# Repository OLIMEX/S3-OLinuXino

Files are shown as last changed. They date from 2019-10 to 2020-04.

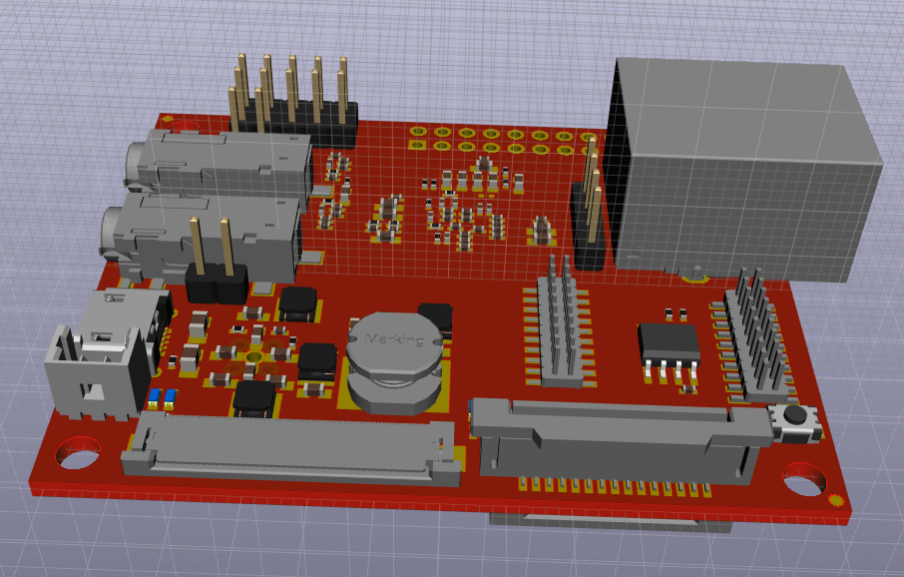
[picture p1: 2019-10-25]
HARDWARE/S3-OLinuXino-Rev_A-preliminary/images/img2.png

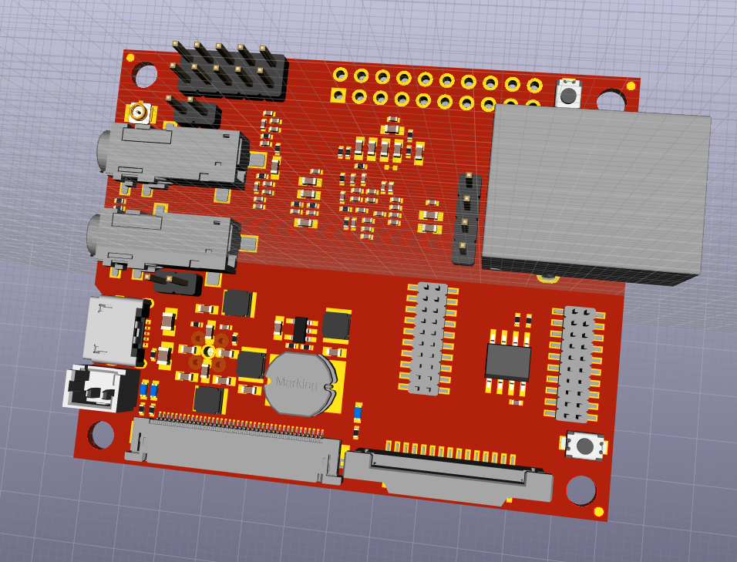
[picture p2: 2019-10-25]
HARDWARE/S3-OLinuXino-Rev_A-preliminary/images/img1.png

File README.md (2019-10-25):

# S3-OLinuXino
IP Camera with S3 SOC from Allwinner, PoE 100Mbit, LCD, micro SD, Flash

This board has:
- Allwinner S3 Cortex-A7 running at 1.2Ghz
- 1Gb DDR3 RAM inside S3 SOC up to 1333Mhz
- 100Mb Ethernet interface with PoE option
- NAND/eMMC/SPI Flash on socket
- WiFi / BT module with RTL8723BS 
- Audio In and Out
- UEXT connector
- Configuration EEPROM
- LCD connector for LCD-OLinuXino
- MIPI camera connector
- CSI camera connector
- Dimensions: 60 x 50 mm

# License
- Hardware is with CERN OHL v1.2 license
- Software is with GPLv3 license
- Documentation is with CC BY-SA 4.0 license

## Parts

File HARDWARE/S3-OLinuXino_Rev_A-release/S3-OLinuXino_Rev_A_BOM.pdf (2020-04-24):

S3-OLinuXino_Rev_A_BOM | 01/03/2020
Qty | Designation | Package | Designator
2 | 0R/R0402(Board_Mounted) | R_0402_5MIL_0R(Board_Mounted) | R34,R53
1 | 0.03R/1%/R1206 | R_1206_5MIL_DWS | R38
10 | 22R/R0402 | R_0402_5MIL_DWS | R8,R9,R12,R20,R22,R50,R54,R55,R62,R63
2 | 240R/1%/R0402 | R_0402_5MIL_DWS | R27,R28
1 | 470R/R0402 | R_0402_5MIL_DWS | R57
1 | 1.1k/1%/R0402 | R_0402_5MIL_DWS | R40
20 | 2.2k/R0402 | R_0402_5MIL_DWS | R1,R2,R3,R4,R5,R6,R14,R15,R16,R18,R21, R24,R25,R29,R30,R35,R47,R52,R58,R59
1 | 3.32k/1%/R0402 | R_0402_5MIL_DWS | R43
2 | 3.9k/1%/R0402 | R_0402_5MIL_DWS | R41,R45
1 | 4.99k/1%/R0402 | R_0402_5MIL_DWS | R42
1 | 6.04k/1%/R0402 | R_0402_5MIL_DWS | R31
1 | 8.25k/1%/R0402 | R_0402_5MIL_DWS | R44
10 | 10k/R0402 | R_0402_5MIL_DWS | R7,R11,R26,R32,R37,R39,R46,R48,R60,R61
1 | 100k/R0402 | R_0402_5MIL_DWS | R10
3 | 200k/1%/R0402 | R_0402_5MIL_DWS | R17,R19,R51
1 | 10M/R0402 | R_0402_5MIL_DWS | R33
1 | RA1206_(4X0603)_4B8_51R | RA1206_(4X0603)_4B8_xx | RM4
3 | RA1206_(4x0603)_4B8_100k | RA1206_(4X0603)_4B8_xx | RM3,RM2,RM1
1 | 0.8pF/50V/+-0.25pF/COG/C0402 | C_0402_5MIL_DWS | C11
1 | 1.5pF/50V/+-0.25pF/COG/C0402 | C_0402_5MIL_DWS | C13
1 | 10pF/50V/5%/COG/C0402 | C_0402_5MIL_DWS | C10
2 | 22pF/50V/5%/COG/C0402 | C_0402_5MIL_DWS | C51,C52
6 | 33pF/50V/5%/COG/C0402 | C_0402_5MIL_DWS | C53,C54,C93,C96,C97,C98
1 | 1nF/50V/10%/X7R/C0402 | C_0402_5MIL_DWS | C21
1 | 1nF/2kV/10%/X7R/C1206 | C_1206_5MIL_DWS_ISO | C65
44 | 100nF/10V/10%/X7R/C0402 | C_0402_5MIL_DWS | C1,C3,C4,C7,C9,C33,C16,C17,C18,C20,C22, C30,C32,C38,C50,C57,C60,C64,C63,C66, C71,C73,C75,C76,C78,C79,C82,C83,C95, C88,C84,C85,C86,C87,C89,C90,C91,C94, C99,C100,C101,C102,C103,C105
1 | 1uF/10V/20%/X5R/C0603 | C_0603_5MIL_DWS | C42
2 | 2.2uF/6.3V/10%/X5R/C0603 | C_0603_5MIL_DWS | C19,C47
9 | 4.7uF/6.3V/20%/X5R/C0603 | C_0603_5MIL_DWS | C24,C28,C37,C43,C44,C45,C46,C48,C49
20 | 10uF/6.3V/20%/X5R/C0603 | C_0603_5MIL_DWS | C6,C8,C14,C15,C29,C31,C34,C35,C36,C39, C40,C41,C55,C59,C67,C68,C74,C77,C81,C92
9 | 47uF/6.3V/20%/X5R/C0805 | C_0805_5MIL_DWS | C12,C25,C26,C27,C56,C58,C61,C69,C70
1 | 3.3nH/+-0.1nH/L0402 (LQP15MN3N3B02D) | L_0402_5MIL_DWS | L1
3 | 2.2uH/1.5A/72mR/20%/CD32 (SPN30302R2MPTE) | CD32 | L3,L4,L5
1 | 2.2uH/1.5A/DCR=72mR/20%/ 3.00x3.00x1.50mm/CD32 (NR3015T2R2M) | CD32 | L7
1 | 2.2uH/4.5A/28mR/20%/CD75/ 7.8x7.0x5.0mm(YS75-2R2M) | YS75_7X8MM | L6
6 | FB0805\600R\2A | L_0805_5MIL_DWS | L2,L8,L9,L10,L11,L12
2 | 1N5822/SS34/SMA | SMA-KA | D3,D4
1 | 1N5819(S4SOD-123) | SOD-123_1C-2A_KA | D1
1 | IRLML6402(SOT-23) | SOT23 | FET1
1 | SMBJ6.0A | DO214AA_1(K)-2(A) | D2
1 | LED/YELLOW/0603 | LED_0603_KA | CHGLED1
1 | LED\Red\0603 | LED_0603_KA | PWRLED1
1 | LED/Red/0603 | LED_0603_KA | GPIO_LED1
1 | DTA114YKA(SOT-23) | SOT23 | T1
1 | Q32.768kHz/12.5pF/2P/SMD1206 | CM7V-T1A(Crystal_Package-1206_3.20x1.50x0.65mm) | Q1
1 | Q24MHZ/20pF/30ppm/4P/ 3.2x2.5mm | TSX-3.2x2.5mm_GND(3) | Q2
1 | AllWinner-S3(FBGA-234) | FBGA-234(Pitch-0.65mm_Pad-0.3mm_11x11x1.08mm) | U1
1 | SY8089AAAC(SOT23-5) | SOT-23-5 | U5
1 | AXP209(QFN-48) | QFN48-6x6mm-OLIMEX_V2 | U4

S3-OLinuXino_Rev_A_BOM | 01/03/2020
1 | RTL8723BS(ComboModule) | RL-SM02BD(RTL8723BS) | U3
1 | AT24C16C-SSHM-T | SOIC-8_150mil | U2
1 | SY6280AAC(SOT23-5) | SOT-23-5 | U6
1 | MT3608(SOT23-6) | SOT23-6 | U7
1 | [2x(HN1x2)+HN1x4] | PoE[2x(HN1x2)+HN1x4] | PoE1
1 | HN2x5 | HN2x5 | UEXT1
1 | Flash[2x(PA-V16X-2X10-LF)] | Flash[2x(PA-V16X-2X10-LF)] | Flash1
1 | DW02S | LIPO_BAT_VERTICAL_DW02S | LiPo_BAT1
1 | FPV-WZA21-40-LF | FPV-WZA21-40-LF | LCD_CON1
1 | LPJG0926HENL(MagJack_ 10_100_1000_with_PoE) | LPJG0926HENL(MagJack_ 10_100_1000_with_PoE) | LAN1
1 | OV2640(FPV-WZB21-24-LF) | OV2640(FPV-WZB21-24-LF) | CAM1
2 | PJ-W47S-05D2-LF | PJ-W47S-05D2-LF_5PIN_V2 | HEADPHONES/LINEOUT1,MIC/LINEIN1
1 | 1.0mm-pitch_ZIF_SMT-15P | TE_1-1734248-5 | RPi_CAMERA1
1 | MICRO_SD(TFC-WPAPR-08) | TFC-WPAPR-08 | MICRO_SD1
1 | U.FL-R-SMT-1 | U.FL-R-SMT-1 | ANT1
1 | MICRO_USB\MISB-SWMM-5B_LF | USB-MICRO_MISB-SWMM-5B_LF | USB-OTG1
2 | IT-1185AU2-160G-G-TR | IT1185AU2_V2 | PWR1,RST1
2 | Soldered(1-2);Opened(2-3) | SJ_2_SMALL | HPHONEOUTL/LINEOUTL1, HPHONEOUTR/LINEOUTR1
2 | Opened(2-3);Soldered(1-2) | SJ_2_SMALL | LINEINR/MICIN1,LINEINL/MICIN1
1 | NA(HN2x10) | HN2x10 | EXT1
1 | NA(15pF/C0402) | C_0402_5MIL_DWS | C104
1 | NA(10uF/6.3V/20%/X5R/C0603) | C_0603_5MIL_DWS | C23
2 | NA | R_0402_5MIL_DWS | R13,R49
2 | NA/R0402 | R_0402_5MIL_DWS | R64,R56
1 | NA(2.2k/R0402) | R_0402_5MIL_DWS | R36

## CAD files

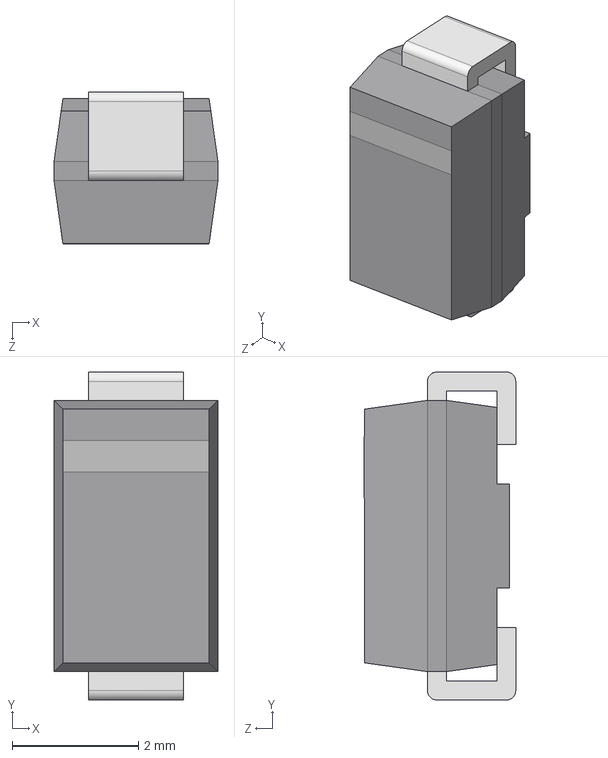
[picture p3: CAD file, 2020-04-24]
HARDWARE/S3-OLinuXino-Rev_A-preliminary/3d/DO-214AC_SMA.step
2.60 x 5.20 x 2.40 mm

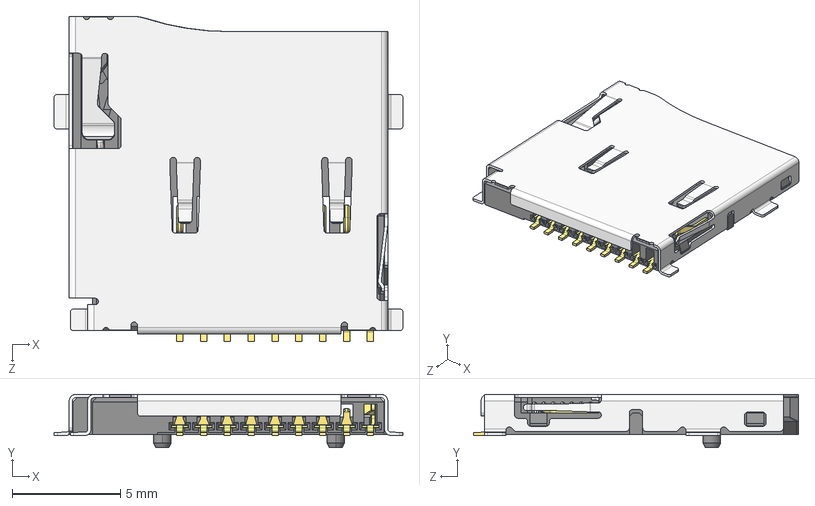
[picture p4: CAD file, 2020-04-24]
HARDWARE/S3-OLinuXino_Rev_A-release/3d/TFC-WPAPR-08---112J-TXAR-R_C_1-1.STEP
16.1 x 2.45 x 15.0 mm

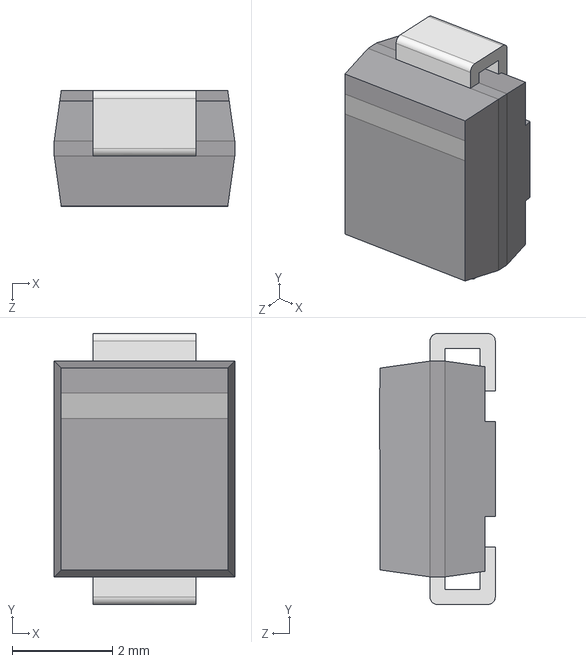
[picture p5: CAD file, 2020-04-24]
HARDWARE/S3-OLinuXino-Rev_A-preliminary/3d/DO-214AA_SMB.step
3.60 x 5.40 x 2.30 mm

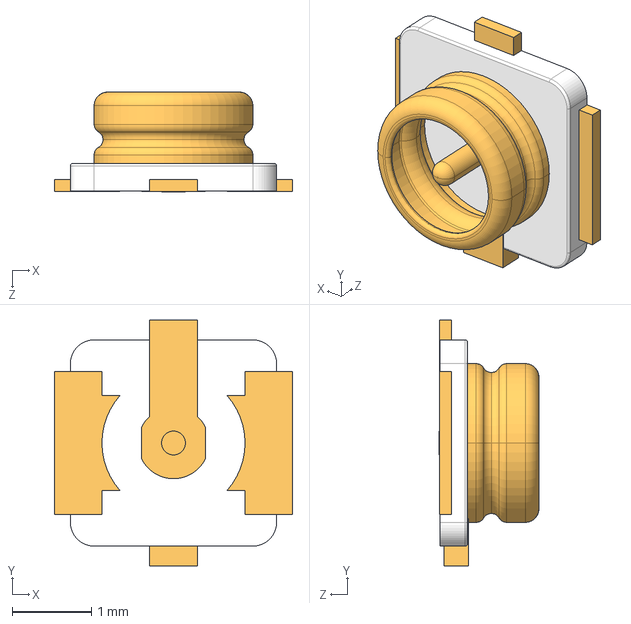
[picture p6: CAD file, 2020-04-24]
HARDWARE/S3-OLinuXino_Rev_A-release/3d/U_FL-R-SMT-1.step
3.00 x 3.10 x 1.26 mm

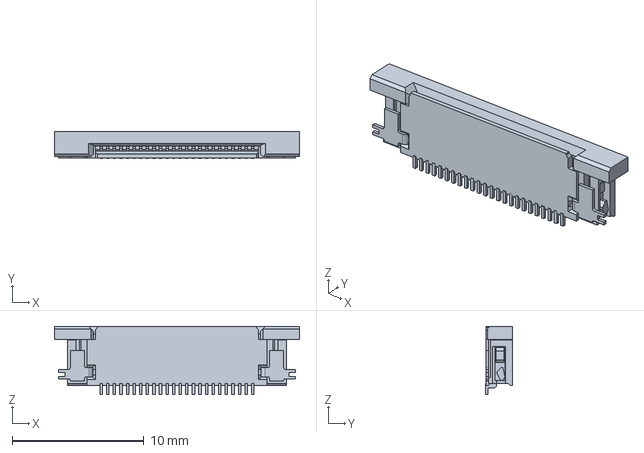
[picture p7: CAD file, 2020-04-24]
HARDWARE/S3-OLinuXino_Rev_A-release/3d/FPV-WZB21-24-LF_Molex-524372433.stp
18.6 x 2.04 x 5.20 mm

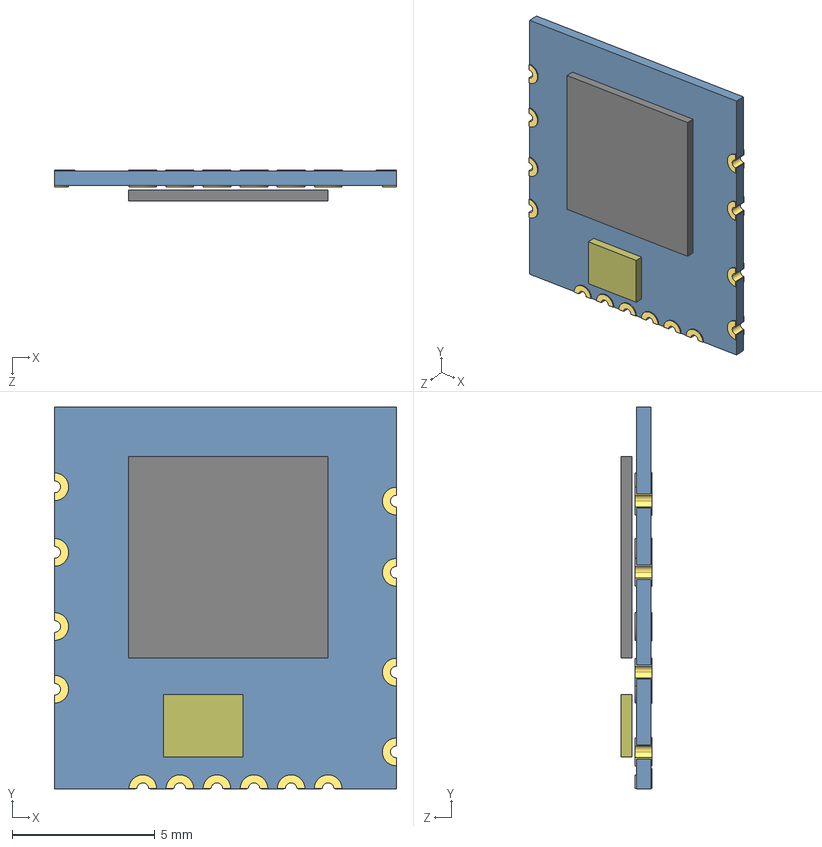
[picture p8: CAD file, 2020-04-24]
HARDWARE/S3-OLinuXino-Rev_A-preliminary/3d/BL-R8723BT1module.STEP
12.0 x 13.4 x 1.10 mm
User Library-BL-R8723BT1 module_Part_113087
User Library-BL-R8723BT1 module_Part_113087_2
User Library-BL-R8723BT1 module_Part_123053
User Library-BL-R8723BT1 module_Part_156259
User Library-BL-R8723BT1 module_Part_126661
User Library-BL-R8723BT1 module_Part_126661_2
User Library-BL-R8723BT1 module_Part_126661_3
User Library-BL-R8723BT1 module_Part_126661_4
User Library-BL-R8723BT1 module_Part_126661_5
User Library-BL-R8723BT1 module_Part_156259_2
User Library-BL-R8723BT1 module_Part_126661_6
User Library-BL-R8723BT1 module_Part_126661_7
User Library-BL-R8723BT1 module_Part_126661_8
User Library-BL-R8723BT1 module_Part_126661_9
User Library-BL-R8723BT1 module_Part_126661_10
User Library-BL-R8723BT1 module_Part_126661_11
User Library-BL-R8723BT1 module_Part_156259_3

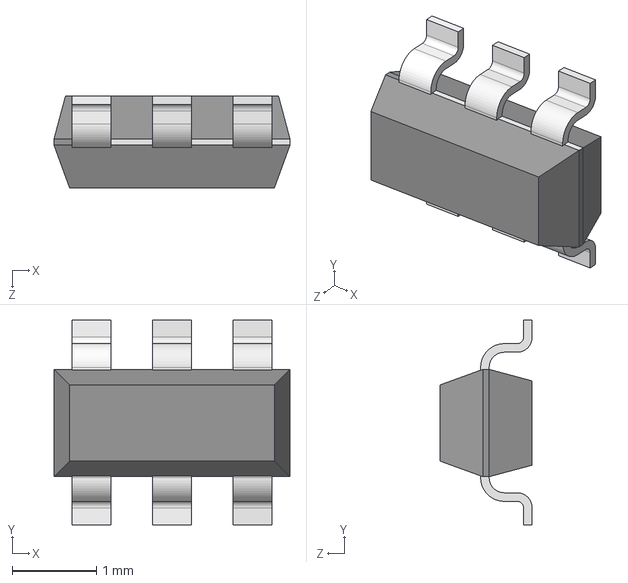
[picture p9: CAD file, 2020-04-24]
HARDWARE/S3-OLinuXino-Rev_A-preliminary/3d/SOT-23-6.step
2.79 x 2.43 x 1.09 mm

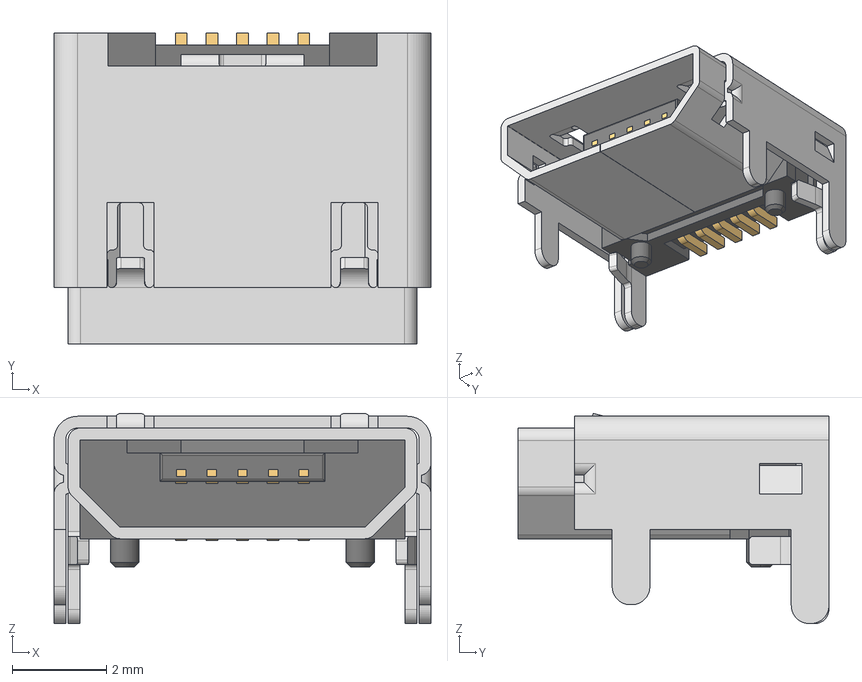
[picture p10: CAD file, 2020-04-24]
HARDWARE/S3-OLinuXino-Rev_A-preliminary/3d/usb_micro_4p.stp
8.00 x 6.60 x 4.46 mm

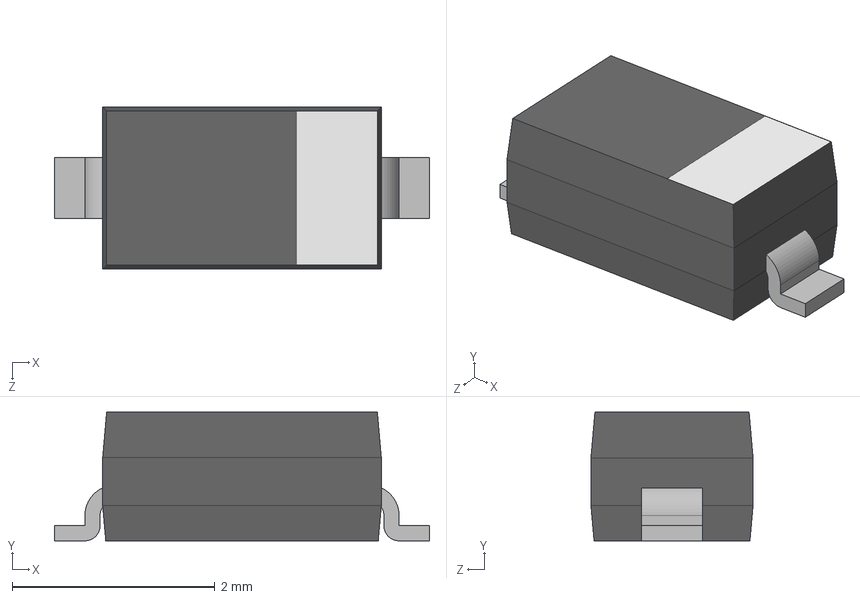
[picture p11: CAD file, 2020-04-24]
HARDWARE/S3-OLinuXino-Rev_A-preliminary/3d/SOD123.step
3.70 x 1.27 x 1.60 mm

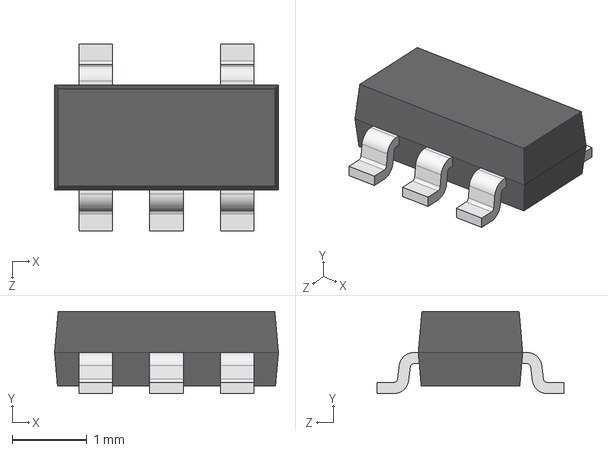
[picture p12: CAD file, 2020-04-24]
HARDWARE/S3-OLinuXino_Rev_A-release/3d/SOT-23-5.step
3.00 x 1.10 x 2.50 mm

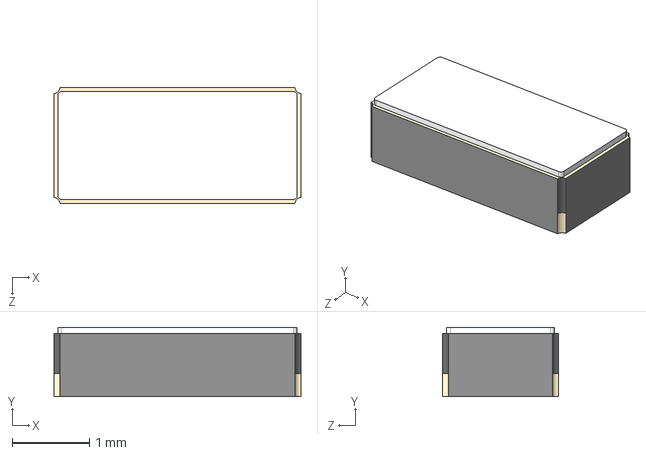
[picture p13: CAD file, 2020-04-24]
HARDWARE/S3-OLinuXino-Rev_A-preliminary/3d/Q32.768kHz_12.5pF_2P_SMD1206---ECS-.327-12.5-34B-C-TR.STEP
3.20 x 0.9 x 1.50 mm

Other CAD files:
HARDWARE/S3-OLinuXino-Rev_A-preliminary/3d/20PinMaleSmt.stp
HARDWARE/S3-OLinuXino-Rev_A-preliminary/3d/BGA-256_11.0x11.0mm_Layout20x20_P0.5mm_Ball0.3mm_Pad0.25mm_NSMD.step
HARDWARE/S3-OLinuXino-Rev_A-preliminary/3d/CUI_SJ-43515TS-SMT-TR.step
HARDWARE/S3-OLinuXino-Rev_A-preliminary/3d/FPV-WZA21-40-LF_Molex-541044033.stp
HARDWARE/S3-OLinuXino-Rev_A-preliminary/3d/HN1x2-PinHeader_1x02_P2.54mm_Vertical.step
HARDWARE/S3-OLinuXino-Rev_A-preliminary/3d/HN1x4-PinHeader_1x04_P2.54mm_Vertical.step
HARDWARE/S3-OLinuXino-Rev_A-preliminary/3d/HN2x5-PinHeader_2x05_P2.54mm_Vertical.step
HARDWARE/S3-OLinuXino-Rev_A-preliminary/3d/L-CD32_shielded.step
HARDWARE/S3-OLinuXino-Rev_A-preliminary/3d/L-CD75(YS75)_7.80x7.00x5.50mm.step
HARDWARE/S3-OLinuXino-Rev_A-preliminary/3d/Molex_PicoBlade_530470210.step
HARDWARE/S3-OLinuXino-Rev_A-preliminary/3d/QFN-48_6x6mm_Pitch-0.4mm.STEP
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

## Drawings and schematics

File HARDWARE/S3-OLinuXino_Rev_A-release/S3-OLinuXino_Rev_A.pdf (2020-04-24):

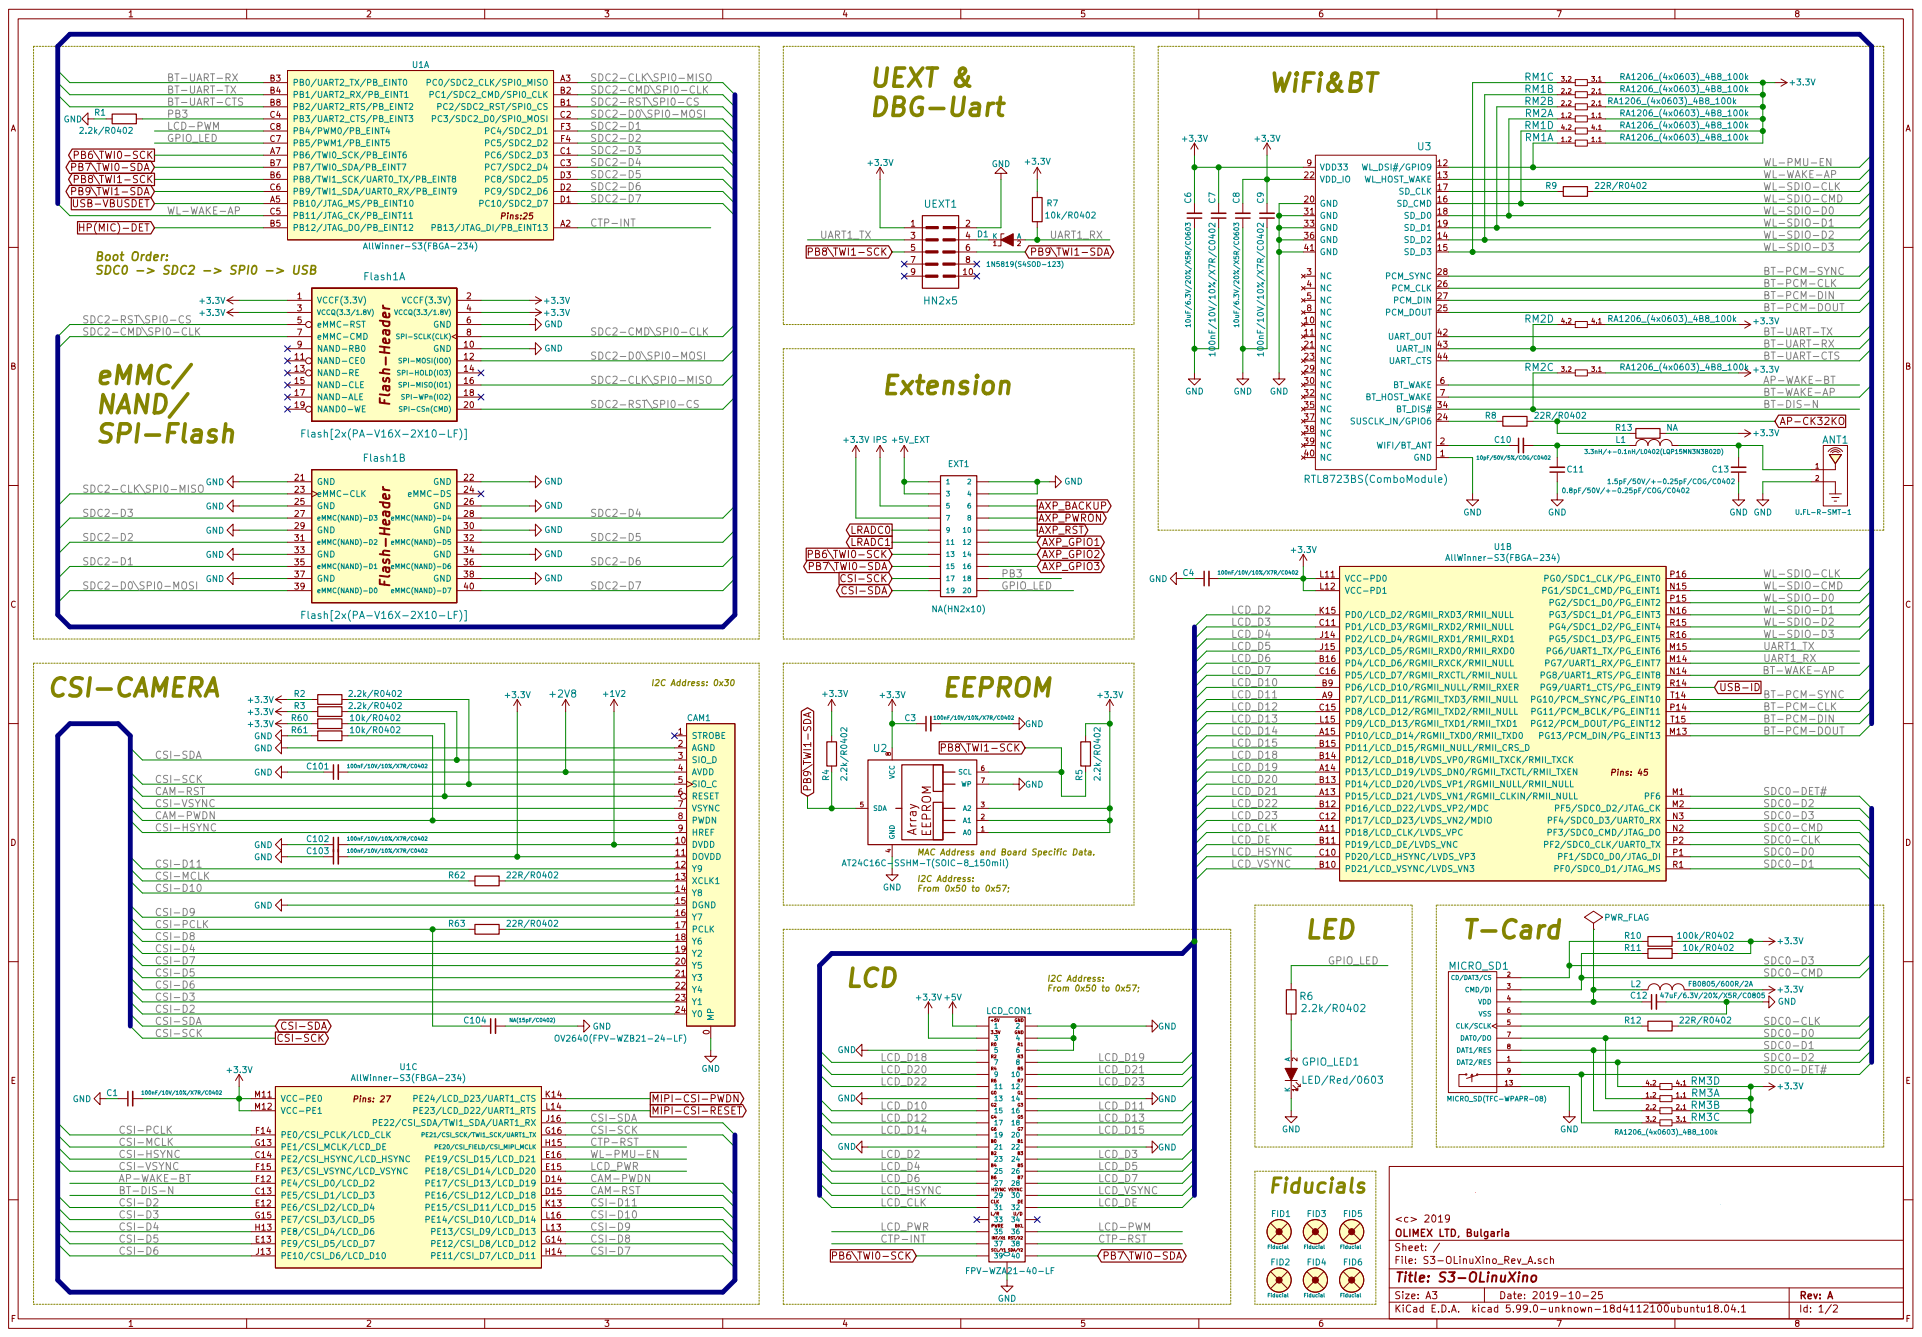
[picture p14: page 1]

BT-UART-RX WL-PMU-EN WL-WAKE-AP WL-SDIO-D3 WL-SDIO-D2 WL-SDIO-D1 WL-SDIO-D0 WL-SDIO-CMD

PB6\TWI0-SCK
PB8\TWI1-SCK
PB9\TWI1-SDA
HP(MIC)-DET USB-VBUSDET

BT-PCM-SYNC
BT-PCM-CLK
BT-PCM-DOUT BT-PCM-DIN

+3.3V GND GND GND GND GND GND

2 ANT1
BT-PCM-DOUT WL-SDIO-CLK

I2C Address: From 0x50 to 0x57; EEPROM

CAM-RST CSI-D7 CSI-D9 CSI-D8 CSI-D10 CSI-D11 CSI-D2 CSI-D3 CSI-D4 CSI-PCLK CSI-VSYNC
CSI-D6 CSI-MCLK CSI-D5 CSI-HSYNC

0 STROBE 1 DVDD 10 DOVDD 11 Y9 12 XCLK1 13 Y8 14 DGND 15 Y7 16 PCLK 17 Y6 18 Y2 19 AGND 2 Y5 20 Y3 21 Y4 22 Y1 23 Y0 24 SIO_D 3 AVDD 4 SIO_C 5 RESET 6 VSYNC 7 PWDN 8 HREF 9 CAM1 OV2640(FPV-WZB21-24-LF)

MAC Address and Board Specific Data. GND

4 SDA 5 SCL 6 WP 7 VCC

2.2k/R0402 MIPI-CSI-RESET MIPI-CSI-PWDN

CSI-MCLK CSI-PCLK

CTP-RST CSI-D9 CAM-PWDN

File: S3-OLinuXino_Rev_A.sch Sheet: / OLIMEX LTD, Bulgaria <c> 2019

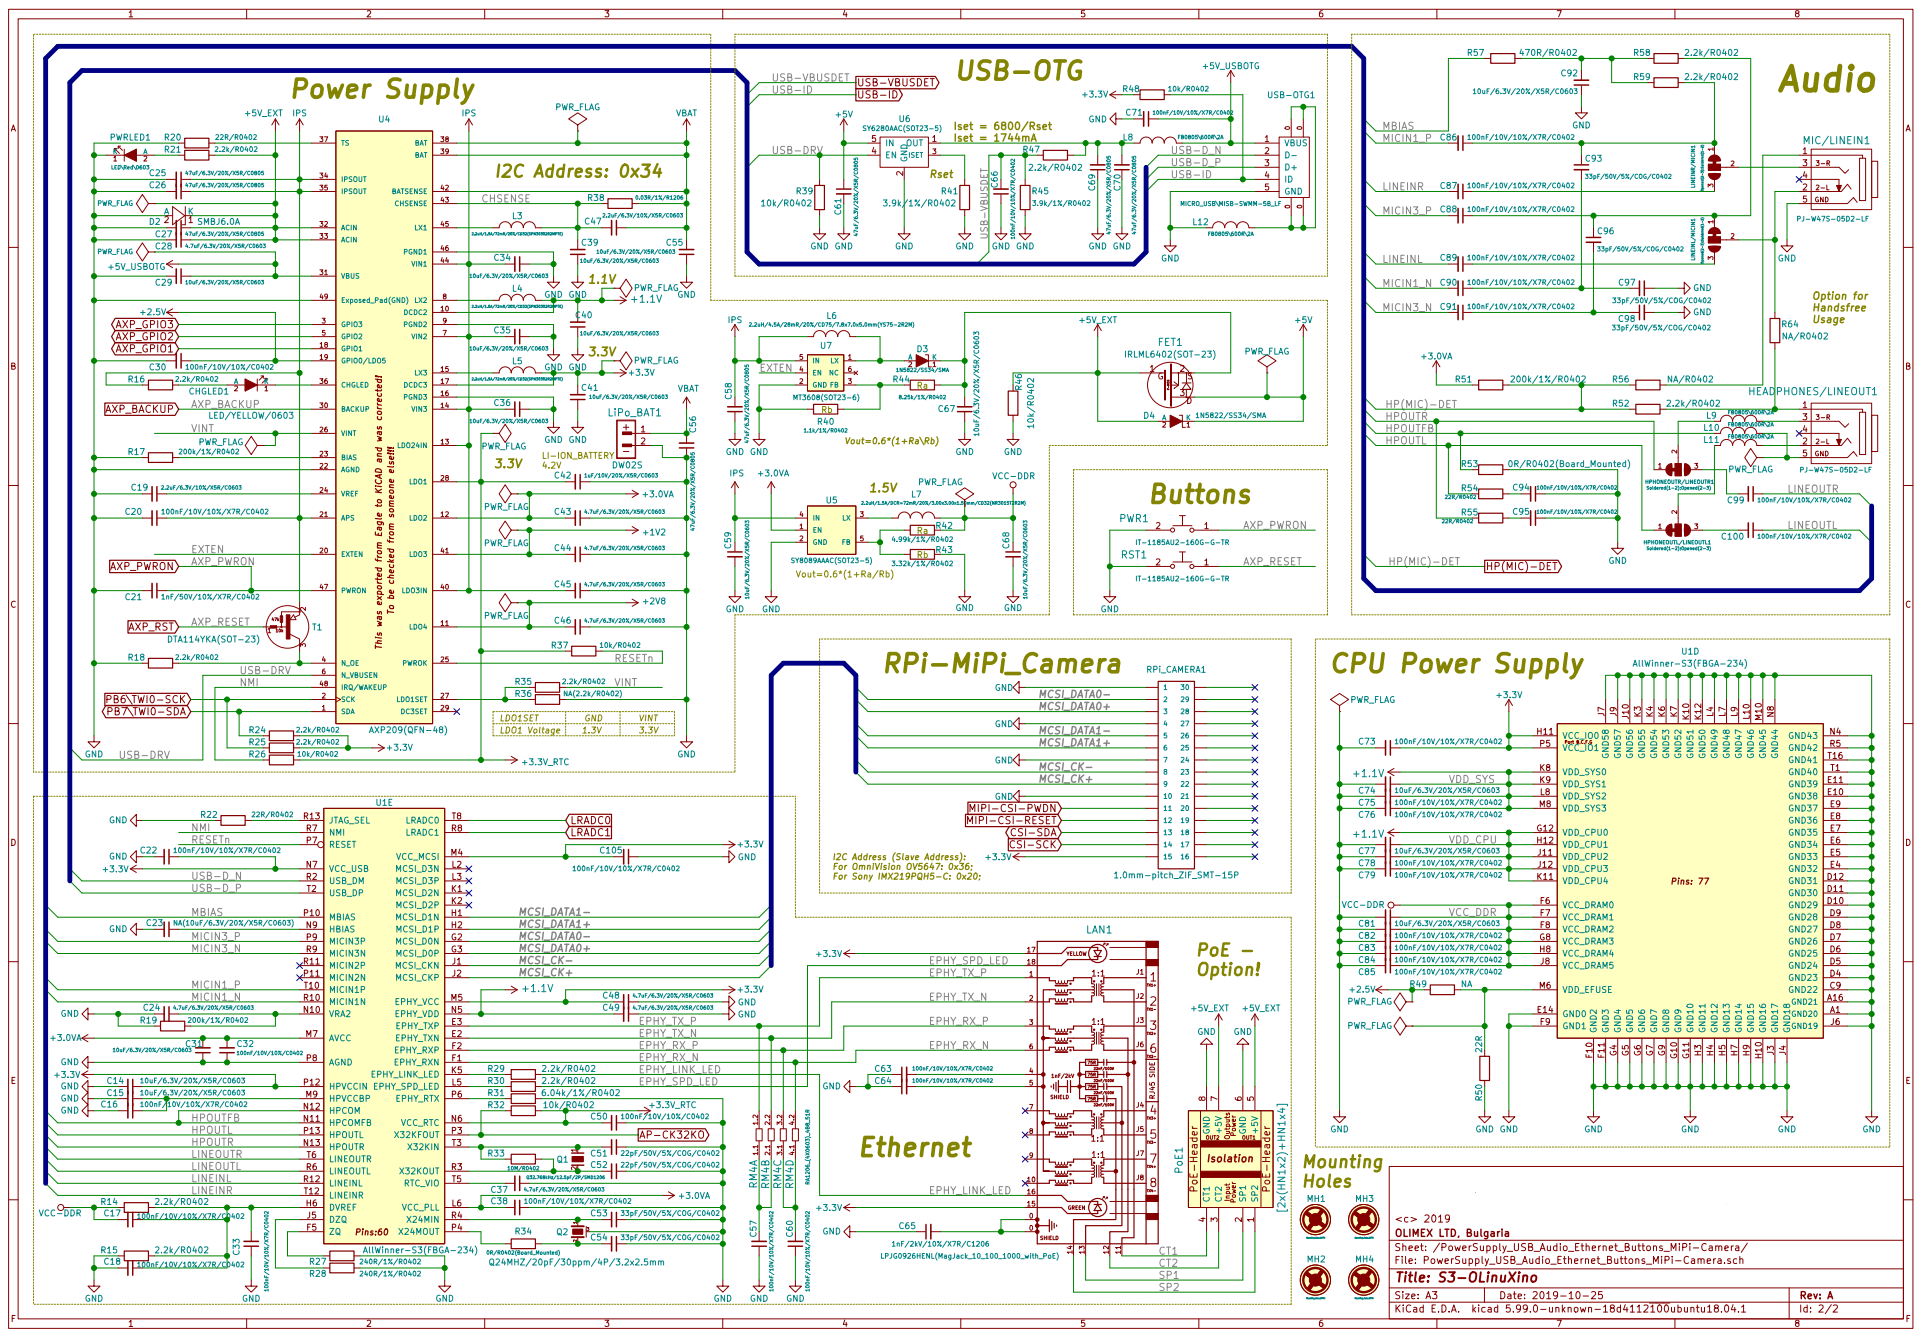
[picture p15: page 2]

File: PowerSupply_USB_Audio_Ethernet_Buttons_MiPi-Camera.sch Sheet: /PowerSupply_USB_Audio_Ethernet_Buttons_MiPi-Camera/ OLIMEX LTD, Bulgaria <c> 2019 Power Supply

33pF/50V/5%/COG/C0402 C97
Option for Handsfree Usage GND GND GND

VCC-DDRR46 10k/R0402 Vout=0.6*(1+Ra\Rb)

CSI-SDA CSI-SCK MCSI_CK- MCSI_DATA1- MCSI_DATA1+ MCSI_CK+ MCSI_DATA0- MCSI_DATA0+

I2C Address (Slave Address): For OmniVision OV5647: 0x36; For Sony IMX219PQH5-C: 0x20; +3.3V_RTC

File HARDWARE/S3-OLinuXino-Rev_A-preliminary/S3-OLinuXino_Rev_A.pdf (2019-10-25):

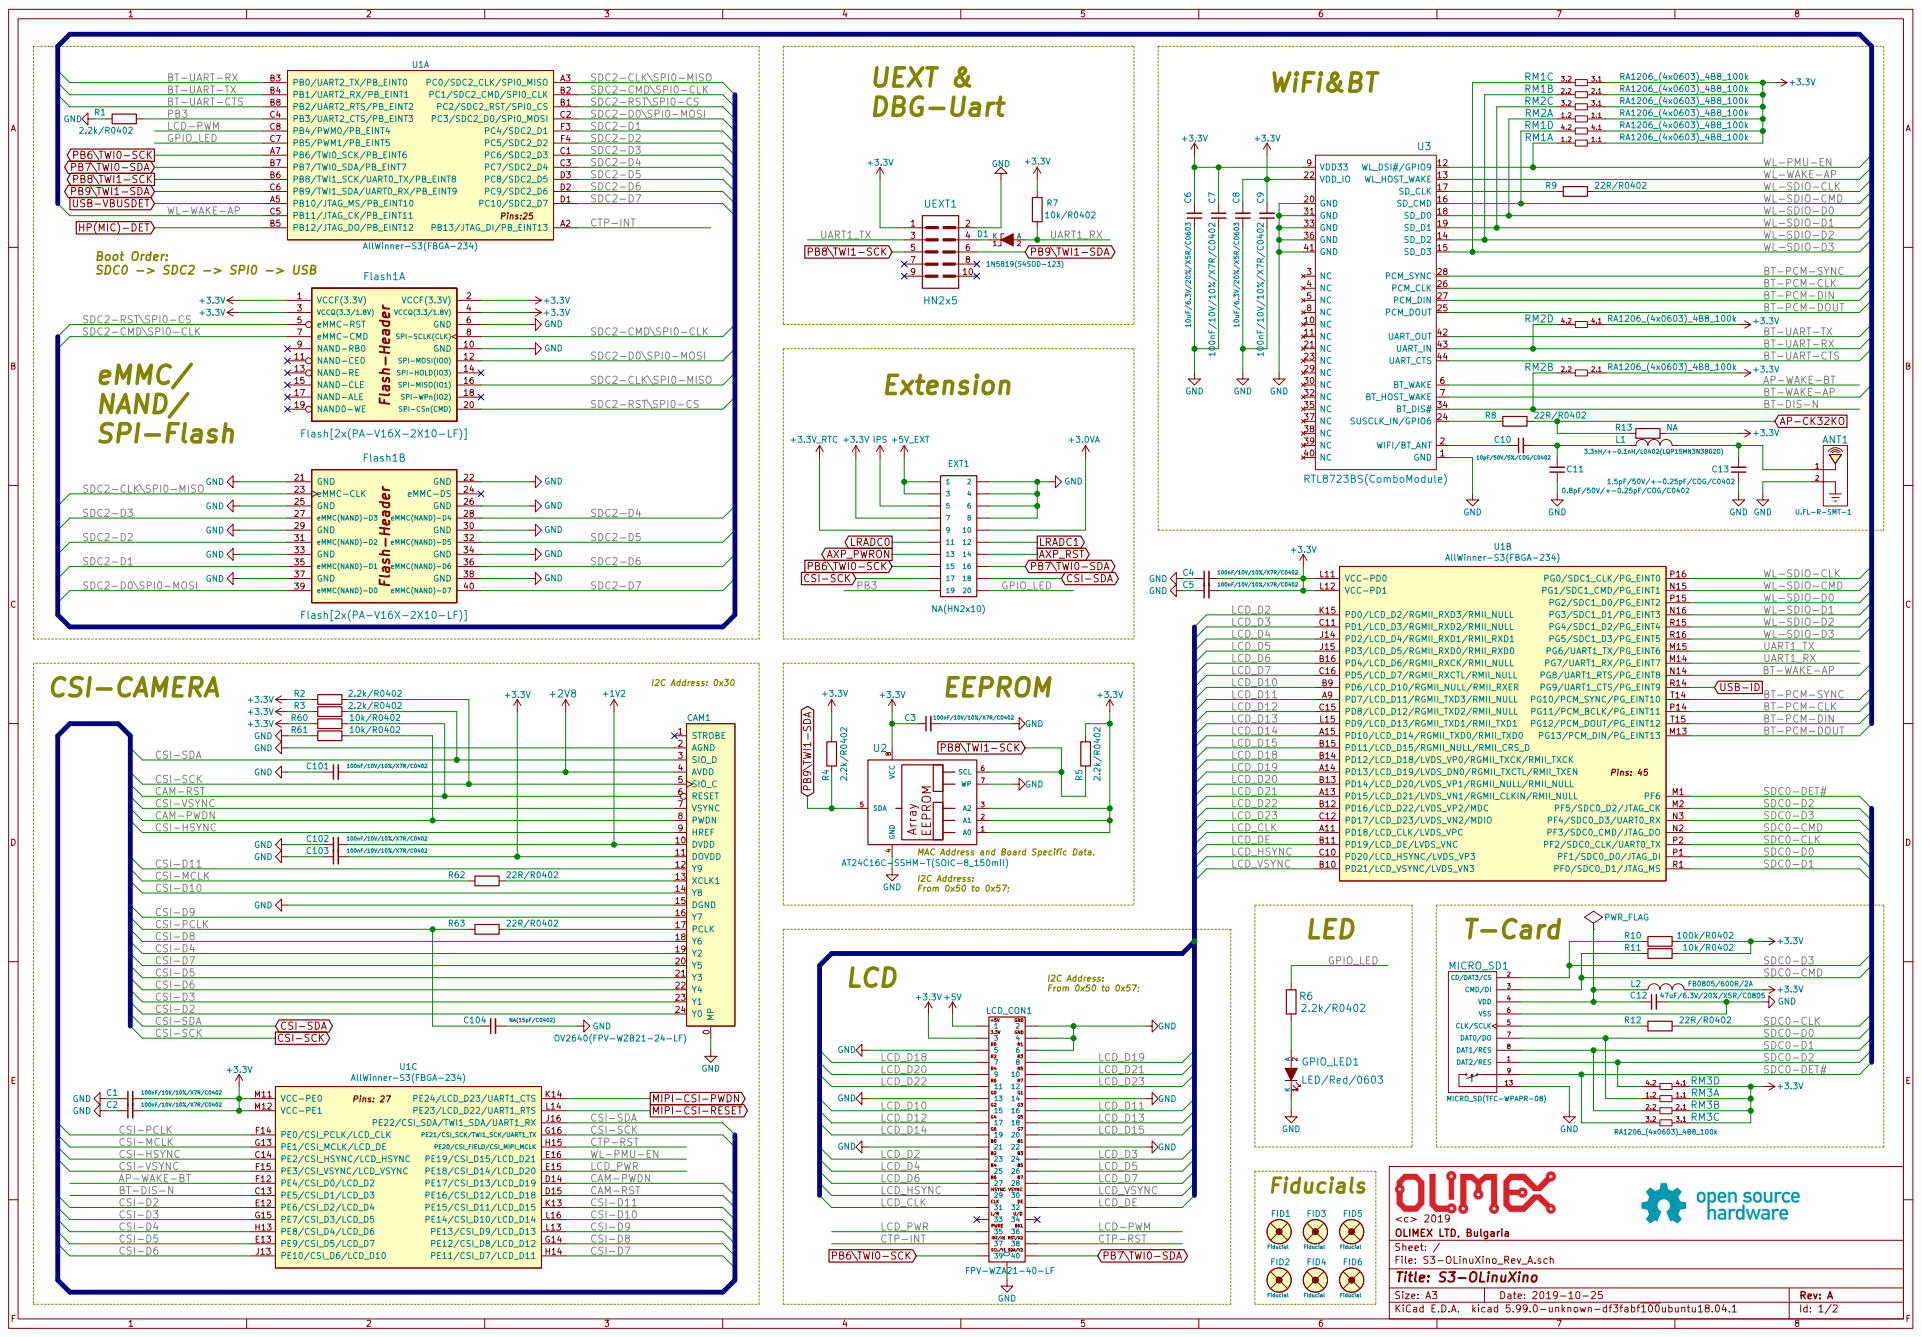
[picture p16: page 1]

BT-UART-RX WL-PMU-EN WL-WAKE-AP WL-SDIO-D3 WL-SDIO-D2 WL-SDIO-D1 WL-SDIO-D0 WL-SDIO-CMD

PB6\TWI0-SCK
PB8\TWI1-SCK
PB9\TWI1-SDA
HP(MIC)-DET USB-VBUSDET

Flash[2x(PA-V16X-2X10-LF)] Boot Order: SDC0 -> SDC2 -> SPI0 -> USB

BT-PCM-SYNC
BT-PCM-CLK
BT-PCM-DOUT BT-PCM-DIN

+3.3V GND GND GND GND GND GND

2 ANT1
BT-PCM-DOUT WL-SDIO-CLK

I2C Address: From 0x50 to 0x57; EEPROM

CAM-RST CSI-D7 CSI-D9 CSI-D8 CSI-D10 CSI-D11 CSI-D2 CSI-D3 CSI-D4 CSI-PCLK CSI-VSYNC
CSI-D6 CSI-MCLK CSI-D5 CSI-HSYNC

0 STROBE 1 DVDD 10 DOVDD 11 Y9 12 XCLK1 13 Y8 14 DGND 15 Y7 16 PCLK 17 Y6 18 Y2 19 AGND 2 Y5 20 Y3 21 Y4 22 Y1 23 Y0 24 SIO_D 3 AVDD 4 SIO_C 5 RESET 6 VSYNC 7 PWDN 8 HREF 9 CAM1 OV2640(FPV-WZB21-24-LF)

MAC Address and Board Specific Data. GND

4 SDA 5 SCL 6 WP 7 VCC

2.2k/R0402 MIPI-CSI-RESET MIPI-CSI-PWDN

CSI-MCLK CSI-PCLK

CTP-RST CSI-D9 CAM-PWDN

File: S3-OLinuXino_Rev_A.sch Sheet: / OLIMEX LTD, Bulgaria <c> 2019

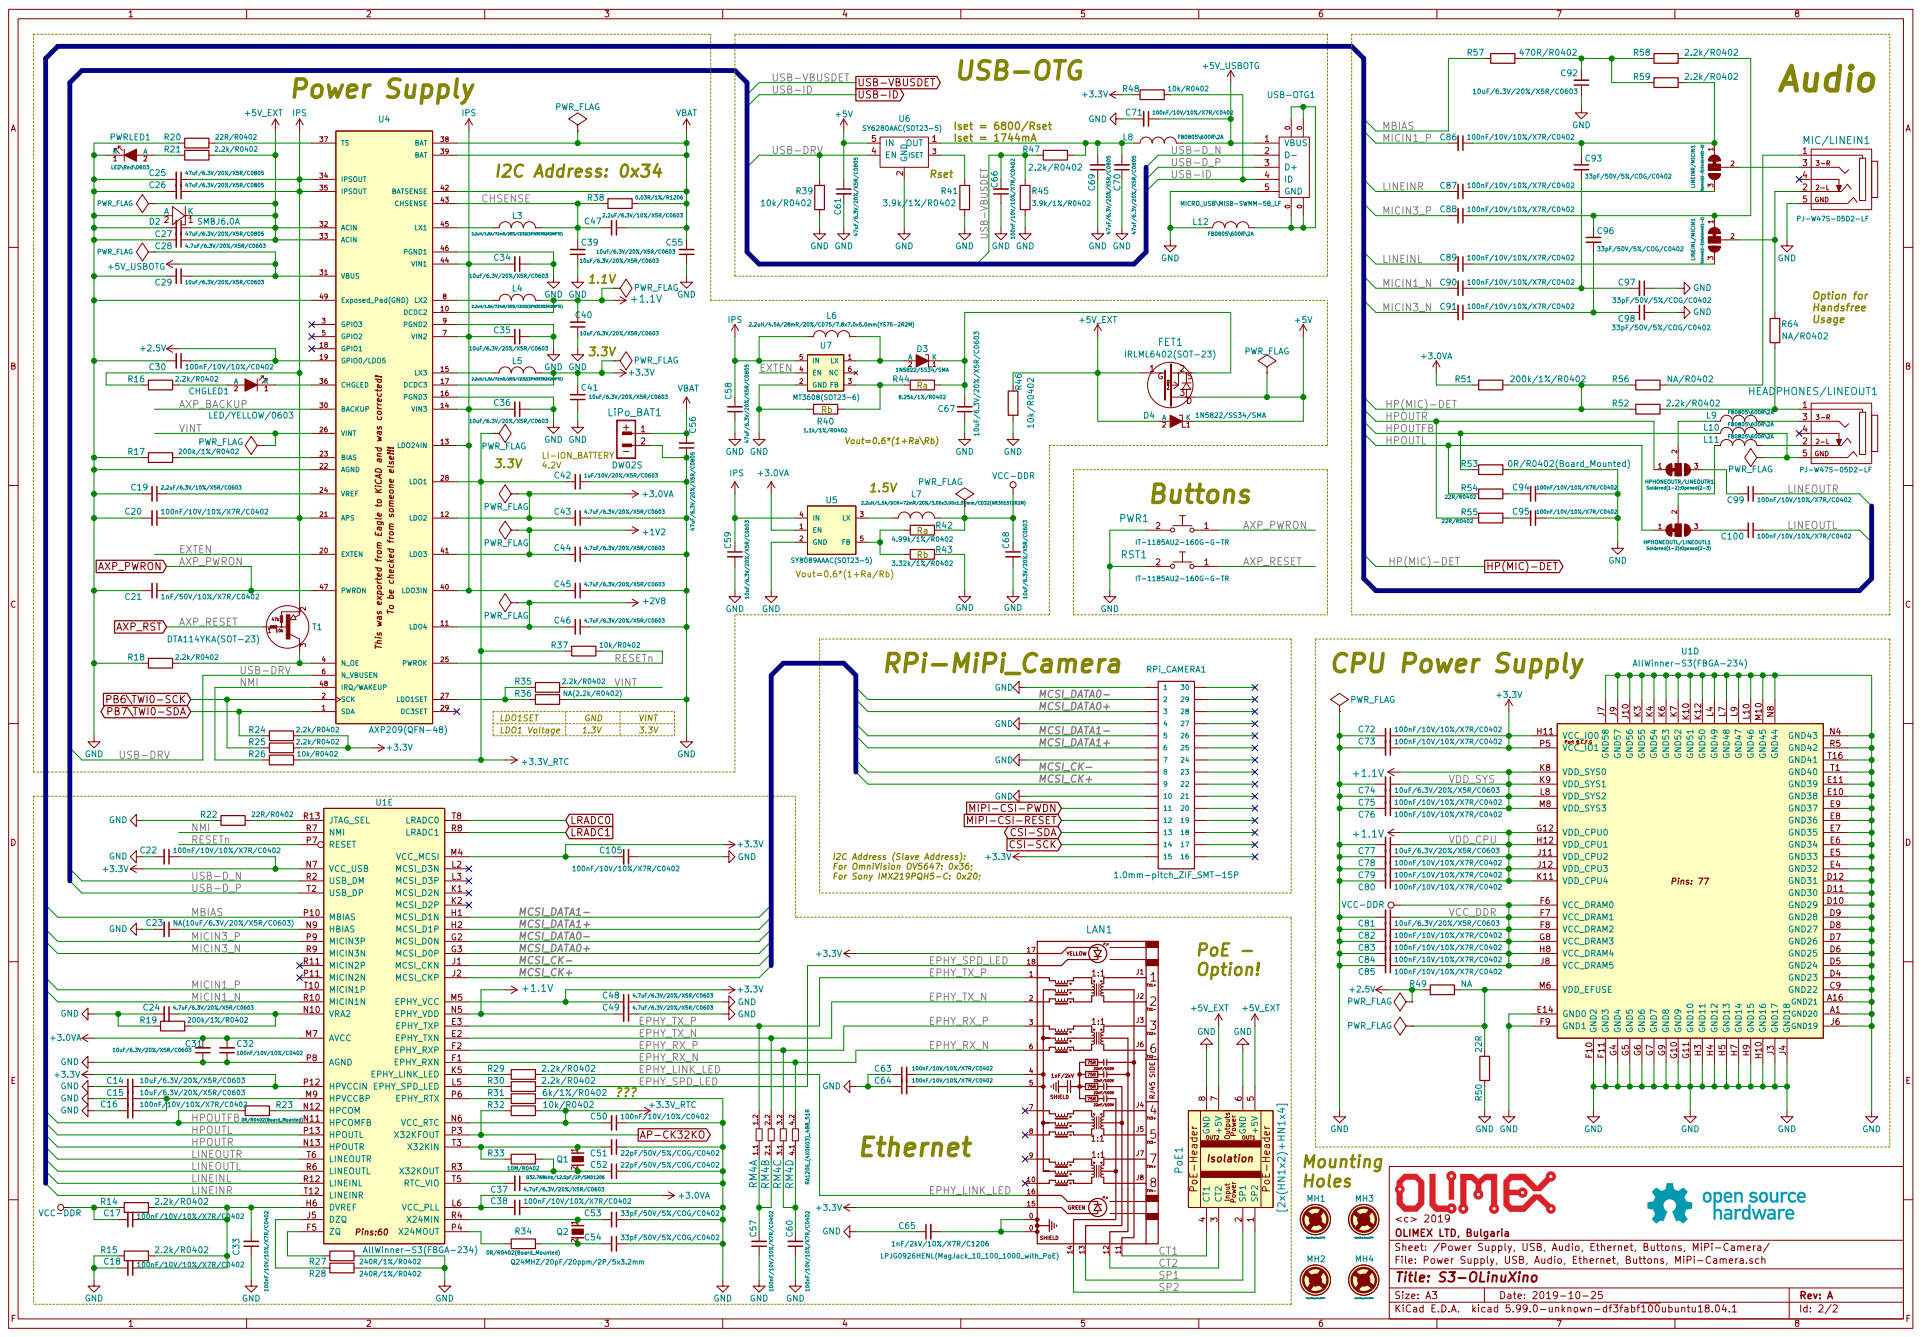
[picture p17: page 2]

File: Power Supply, USB, Audio, Ethernet, Buttons, MiPi-Camera.sch Sheet: /Power Supply, USB, Audio, Ethernet, Buttons, MiPi-Camera/ OLIMEX LTD, Bulgaria <c> 2019 Power Supply

33pF/50V/5%/COG/C0402 C97
Option for Handsfree Usage GND GND GND

VCC-DDRR46 10k/R0402 Vout=0.6*(1+Ra\Rb)

CSI-SDA CSI-SCK MCSI_CK- MCSI_DATA1- MCSI_DATA1+ MCSI_CK+ MCSI_DATA0- MCSI_DATA0+

I2C Address (Slave Address): For OmniVision OV5647: 0x36; For Sony IMX219PQH5-C: 0x20; +3.3V_RTC

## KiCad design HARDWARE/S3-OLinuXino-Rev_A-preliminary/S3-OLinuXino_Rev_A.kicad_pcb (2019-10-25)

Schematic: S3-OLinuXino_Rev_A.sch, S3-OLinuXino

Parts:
ANT1: U.FL-R-SMT-1
C1, C2, C3, C4, C5, C7, C9, C101, C102, C103: 100nF/10V/10%/X7R/C0402; C_0402_5MIL_DWS
C6, C8: 10uF/6.3V/20%/X5R/C0603; C_0603_5MIL_DWS
C10: 10pF/50V/5%/COG/C0402; C_0402_5MIL_DWS
C11: 0.8pF/50V/+-0.25pF/COG/C0402; C_0402_5MIL_DWS
C12: 47uF/6.3V/20%/X5R/C0805; C_0805_5MIL_DWS
C13: 1.5pF/50V/+-0.25pF/COG/C0402; C_0402_5MIL_DWS
C104: NA(15pF/C0402); C_0402_5MIL_DWS
CAM1: OV2640(FPV-WZB21-24-LF)
D1: 1N5819(S4SOD-123); SOD-123_1C-2A_KA
EXT1: NA(HN2x10); HN2x10
FID1, FID2, FID3, FID4, FID5, FID6: Fiducial; Fiducial1x3
Flash1: Flash[2x(PA-V16X-2X10-LF)]
GPIO_LED1: LED/Red/0603; LED_0603_KA
L1: 3.3nH/+-0.1nH/L0402(LQP15MN3N3B02D); L_0402_5MIL_DWS
L2: FB0805/600R/2A; L_0805_5MIL_DWS
LCD_CON1: FPV-WZA21-40-LF
MICRO_SD1: MICRO_SD(TFC-WPAPR-08); TFC-WPAPR-08
R1, R2, R3, R4, R5, R6: 2.2k/R0402; R_0402_5MIL_DWS
R7, R11, R60, R61: 10k/R0402; R_0402_5MIL_DWS
R8, R9, R12, R62, R63: 22R/R0402; R_0402_5MIL_DWS
R10: 100k/R0402; R_0402_5MIL_DWS
R13: NA; R_0402_5MIL_DWS
RM1, RM2, RM3: RA1206_(4x0603)_4B8_100k; RA1206_(4X0603)_4B8_xx
U1: AllWinner-S3(FBGA-234); FBGA-234(Pitch-0.65mm_Pad-0.3mm_11x11x1.08mm)
U2: AT24C16C-SSHM-T(SOIC-8_150mil); SOIC-8_150mil
U3: RTL8723BS(ComboModule); RL-SM02BD(RTL8723BS)
UEXT1: HN2x5

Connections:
+1V2: C102.2, CAM1.10; also elsewhere on the board
+2V8: C101.2, CAM1.4; also elsewhere on the board
+3.0VA: EXT1.10; also elsewhere on the board
+3.3V_RTC: EXT1.9; also elsewhere on the board
+3V3: C1.2, C2.2, C3.1, C4.2, C5.2, C6.2, C7.2, C8.2, C9.2, C103.2, CAM1.11, EXT1.7, Flash1.1, Flash1.2, Flash1.3, Flash1.4, L2.1, LCD_CON1.3, R2.2, R3.2, R4.2, R5.2, R7.2, R10.2, R11.2, R13.2, R60.2, RM1.1.1, RM1.2.1, RM1.3.1, RM1.4.1, RM2.1.1, RM2.2.1, RM2.3.1, RM2.4.1, RM3.1.1, RM3.2.1, RM3.3.1, RM3.4.1, U1.L11 (VCC-PD0), U1.L12 (VCC-PD1), U1.M11 (VCC-PE0), U1.M12 (VCC-PE1), U2.1, U2.2, U2.3, U2.8, U3.9, U3.22, UEXT1.1; also elsewhere on the board
+5V: LCD_CON1.1; also elsewhere on the board
+5V_EXT: EXT1.1, EXT1.3; also elsewhere on the board
/AP-WAKE-BT: U1.F12 (PE4/CSI_D0/LCD_D2), U3.6
/BT-DIS-N: RM2.2.2, U1.C13 (PE5/CSI_D1/LCD_D3), U3.34
/BT-PCM-CLK: U1.P14 (PG11/PCM_BCLK/PG_EINT11), U3.26
/BT-PCM-DIN: U1.T15 (PG12/PCM_DOUT/PG_EINT12), U3.27
/BT-PCM-DOUT: U1.M13 (PG13/PCM_DIN/PG_EINT13), U3.25
/BT-PCM-SYNC: U1.T14 (PG10/PCM_SYNC/PG_EINT10), U3.28
/BT-UART-CTS: U1.B8 (PB2/UART2_RTS/PB_EINT2), U3.44
/BT-UART-RX: RM2.4.2, U1.B3 (PB0/UART2_TX/PB_EINT0), U3.43
/BT-UART-TX: U1.B4 (PB1/UART2_RX/PB_EINT1), U3.42
/BT-WAKE-AP: U1.N14 (PG8/UART1_RTS/PG_EINT8), U3.7
/CAM-PWDN: CAM1.8, R61.1, U1.D14 (PE17/CSI_D13/LCD_D19)
/CAM-RST: CAM1.6, R60.1, U1.D15 (PE16/CSI_D12/LCD_D18)
/CSI-D2: CAM1.24, U1.E12 (PE6/CSI_D2/LCD_D4)
/CSI-D3: CAM1.23, U1.G15 (PE7/CSI_D3/LCD_D5)
/CSI-D4: CAM1.19, U1.H13 (PE8/CSI_D4/LCD_D6)
/CSI-D5: CAM1.21, U1.E13 (PE9/CSI_D5/LCD_D7)
/CSI-D6: CAM1.22, U1.J13 (PE10/CSI_D6/LCD_D10)
/CSI-D7: CAM1.20, U1.H14 (PE11/CSI_D7/LCD_D11)
/CSI-D8: CAM1.18, U1.G14 (PE12/CSI_D8/LCD_D12)
/CSI-D9: CAM1.16, U1.L13 (PE13/CSI_D9/LCD_D13)
/CSI-D10: CAM1.14, U1.L16 (PE14/CSI_D10/LCD_D14)
/CSI-D11: CAM1.12, U1.K13 (PE15/CSI_D11/LCD_D15)
/CSI-HSYNC: CAM1.9, U1.C14 (PE2/CSI_HSYNC/LCD_HSYNC)
/CSI-MCLK: R62.2, U1.G13 (PE1/CSI_MCLK/LCD_DE)
/CSI-PCLK: C104.1, R63.2, U1.F14 (PE0/CSI_PCLK/LCD_CLK)
/CSI-VSYNC: CAM1.7, U1.F15 (PE3/CSI_VSYNC/LCD_VSYNC)
/CTP-INT: LCD_CON1.37, U1.A2 (PB13/JTAG_DI/PB_EINT13)
/CTP-RST: LCD_CON1.38, U1.H15 (PE20/CSI_FIELD/CSI_MIPI_MCLK)
/GPIO_LED: EXT1.20, R6.1, U1.C7 (PB5/PWM1/PB_EINT5)
/LCD-PWM: LCD_CON1.36, U1.C8 (PB4/PWM0/PB_EINT4)
/LCD_CLK: LCD_CON1.31, U1.A11 (PD18/LCD_CLK/LVDS_VPC)
/LCD_D2: LCD_CON1.23, U1.K15 (PD0/LCD_D2/RGMII_RXD3/RMII_NULL)
/LCD_D3: LCD_CON1.24, U1.C11 (PD1/LCD_D3/RGMII_RXD2/RMII_NULL)
/LCD_D4: LCD_CON1.25, U1.J14 (PD2/LCD_D4/RGMII_RXD1/RMII_RXD1)
/LCD_D5: LCD_CON1.26, U1.J15 (PD3/LCD_D5/RGMII_RXD0/RMII_RXD0)
/LCD_D6: LCD_CON1.27, U1.B16 (PD4/LCD_D6/RGMII_RXCK/RMII_NULL)
/LCD_D7: LCD_CON1.28, U1.C16 (PD5/LCD_D7/RGMII_RXCTL/RMII_NULL)
/LCD_D10: LCD_CON1.15, U1.B9 (PD6/LCD_D10/RGMII_NULL/RMII_RXER)
/LCD_D11: LCD_CON1.16, U1.A9 (PD7/LCD_D11/RGMII_TXD3/RMII_NULL)
/LCD_D12: LCD_CON1.17, U1.C15 (PD8/LCD_D12/RGMII_TXD2/RMII_NULL)
/LCD_D13: LCD_CON1.18, U1.L15 (PD9/LCD_D13/RGMII_TXD1/RMII_TXD1)
/LCD_D14: LCD_CON1.19, U1.A15 (PD10/LCD_D14/RGMII_TXD0/RMII_TXD0)
/LCD_D15: LCD_CON1.20, U1.B15 (PD11/LCD_D15/RGMII_NULL/RMII_CRS_D)
/LCD_D18: LCD_CON1.7, U1.B14 (PD12/LCD_D18/LVDS_VP0/RGMII_TXCK/RMII_T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)
/LCD_D19: LCD_CON1.8, U1.A14 (PD13/LCD_D19/LVDS_DN0/RGMII_TXCTL/RMII_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)
/LCD_D20: LCD_CON1.9, U1.B13 (PD14/LCD_D20/LVDS_VP1/RGMII_NULL/RMII_N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)
/LCD_D21: LCD_CON1.10, U1.A13 (PD15/LCD_D21/LVDS_VN1/RGMII_CLKIN/RMII_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)
/LCD_D22: LCD_CON1.11, U1.B12 (PD16/LCD_D22/LVDS_VP2/MDC)
/LCD_D23: LCD_CON1.12, U1.C12 (PD17/LCD_D23/LVDS_VN2/MDIO)
/LCD_DE: LCD_CON1.32, U1.B11 (PD19/LCD_DE/LVDS_VNC)
/LCD_HSYNC: LCD_CON1.29, U1.C10 (PD20/LCD_HSYNC/LVDS_VP3)
/LCD_PWR: LCD_CON1.35, U1.E15 (PE18/CSI_D14/LCD_D20)
/LCD_VSYNC: LCD_CON1.30, U1.B10 (PD21/LCD_VSYNC/LVDS_VN3)
/PB3: EXT1.19, R1.2, U1.C4 (PB3/UART2_CTS/PB_EINT3)
/SDC0-CLK: R12.2, U1.P2 (PF2/SDC0_CLK/UART0_TX)
/SDC0-CMD: MICRO_SD1.3, R11.1, U1.N2 (PF3/SDC0_CMD/JTAG_DO)
/SDC0-D0: MICRO_SD1.7, RM3.1.2, U1.P1 (PF1/SDC0_D0/JTAG_DI)
/SDC0-D1: MICRO_SD1.8, RM3.2.2, U1.R1 (PF0/SDC0_D1/JTAG_MS)
/SDC0-D2: MICRO_SD1.1, RM3.4.2, U1.M2 (PF5/SDC0_D2/JTAG_CK)
/SDC0-D3: MICRO_SD1.2, R10.1, U1.N3 (PF4/SDC0_D3/UART0_RX)
/SDC0-DET#: MICRO_SD1.9, RM3.3.2, U1.M1 (PF6)
/SDC2-CLK\SPI0-MISO: Flash1.16, Flash1.23, U1.A3 (PC0/SDC2_CLK/SPI0_MISO)
/SDC2-CMD\SPI0-CLK: Flash1.7, Flash1.8, U1.B2 (PC1/SDC2_CMD/SPI0_CLK)
/SDC2-D0\SPI0-MOSI: Flash1.12, Flash1.39, U1.C2 (PC3/SDC2_D0/SPI0_MOSI)
/SDC2-D1: Flash1.35, U1.F3 (PC4/SDC2_D1)
/SDC2-D2: Flash1.31, U1.F4 (PC5/SDC2_D2)
/SDC2-D3: Flash1.27, U1.C1 (PC6/SDC2_D3)
/SDC2-D4: Flash1.28, U1.C3 (PC7/SDC2_D4)
/SDC2-D5: Flash1.32, U1.D3 (PC8/SDC2_D5)
/SDC2-D6: Flash1.36, U1.D2 (PC9/SDC2_D6)
/SDC2-D7: Flash1.40, U1.D1 (PC10/SDC2_D7)
/SDC2-RST\SPI0-CS: Flash1.5, Flash1.20, U1.B1 (PC2/SDC2_RST/SPI0_CS)
/UART1_RX: D1.2, R7.1, U1.M14 (PG7/UART1_RX/PG_EINT7)
/UART1_TX: U1.M15 (PG6/UART1_TX/PG_EINT6), UEXT1.3
/WL-PMU-EN: RM1.1.2, U1.E16 (PE19/CSI_D15/LCD_D21), U3.12
/WL-SDIO-CLK: R9.2, U1.P16 (PG0/SDC1_CLK/PG_EINT0)
/WL-SDIO-CMD: RM1.4.2, U1.N15 (PG1/SDC1_CMD/PG_EINT1), U3.16
/WL-SDIO-D0: RM2.1.2, U1.P15 (PG2/SDC1_D0/PG_EINT2), U3.18
/WL-SDIO-D1: RM2.3.2, U1.N16 (PG3/SDC1_D1/PG_EINT3), U3.19
/WL-SDIO-D2: RM1.2.2, U1.R15 (PG4/SDC1_D2/PG_EINT4), U3.14
/WL-SDIO-D3: RM1.3.2, U1.R16 (PG5/SDC1_D3/PG_EINT5), U3.15
/WL-WAKE-AP: U1.C5 (PB11/JTAG_CK/PB_EINT11), U3.13
AP-CK32KO: R8.2, R13.1; also elsewhere on the board
AXP_PWRON: EXT1.13; also elsewhere on the board
AXP_RST: EXT1.14; also elsewhere on the board
CSI-SCK: CAM1.5, EXT1.17, R2.1, U1.G16 (PE21/CSI_SCK/TWI1_SCK/UART1_TX); also elsewhere on the board
CSI-SDA: CAM1.3, EXT1.18, R3.1, U1.J16 (PE22/CSI_SDA/TWI1_SDA/UART1_RX); also elsewhere on the board
GND: ANT1.2, C1.1, C2.1, C3.2, C4.1, C5.1, C6.1, C7.1, C8.1, C9.1, C11.1, C12.2, C13.1, C101.1, C102.1, C103.1, C104.2, CAM1.0, CAM1.2, CAM1.15, EXT1.2, EXT1.4, EXT1.6, EXT1.8, Flash1.6, Flash1.10, Flash1.21, Flash1.22, Flash1.25, Flash1.26, Flash1.29, Flash1.30, Flash1.33, Flash1.34, Flash1.37, Flash1.38, GPIO_LED1.1, LCD_CON1.0, LCD_CON1.2, LCD_CON1.4, LCD_CON1.5, LCD_CON1.6, LCD_CON1.13, LCD_CON1.14, LCD_CON1.21, LCD_CON1.22, MICRO_SD1.6, MICRO_SD1.10, MICRO_SD1.11, MICRO_SD1.12, MICRO_SD1.13, R1.1, R61.2, U2.4, U2.7, U3.1, U3.20, U3.31, U3.33, U3.36, U3.41, UEXT1.2; also elsewhere on the board
HP(MIC)-DET: U1.B5 (PB12/JTAG_DO/PB_EINT12); also elsewhere on the board
IPS: EXT1.5; also elsewhere on the board
LRADC0: EXT1.11; also elsewhere on the board
LRADC1: EXT1.12; also elsewhere on the board
MIPI-CSI-PWDN: U1.K14 (PE24/LCD_D23/UART1_CTS); also elsewhere on the board
MIPI-CSI-RESET: U1.L14 (PE23/LCD_D22/UART1_RTS); also elsewhere on the board
unnamed: ANT1.1, C13.2, L1.1
unnamed: C10.1, U3.2
unnamed: C10.2, C11.2, L1.2
unnamed: C12.1, L2.2, MICRO_SD1.4
unnamed: CAM1.13, R62.1
unnamed: CAM1.17, R63.1
unnamed: D1.1, UEXT1.4
unnamed: GPIO_LED1.2, R6.2
unnamed: MICRO_SD1.5, R12.1
unnamed: R8.1, U3.24
unnamed: R9.1, U3.17
PB6\TWI0-SCK: EXT1.15, LCD_CON1.39, U1.A7 (PB6/TWI0_SCK/PB_EINT6); also elsewhere on the board
PB7\TWI0-SDA: EXT1.16, LCD_CON1.40, U1.B7 (PB7/TWI0_SDA/PB_EINT7); also elsewhere on the board
PB8\TWI1-SCK: R5.1, U1.B6 (PB8/TWI1_SCK/UART0_TX/PB_EINT8), U2.6, UEXT1.5
PB9\TWI1-SDA: R4.1, U1.C6 (PB9/TWI1_SDA/UART0_RX/PB_EINT9), U2.5, UEXT1.6
USB-ID: U1.R14 (PG9/UART1_CTS/PG_EINT9); also elsewhere on the board
USB-VBUSDET: U1.A5 (PB10/JTAG_MS/PB_EINT10); also elsewhere on the board

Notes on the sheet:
T-Card
LCD
MAC Address and Board Specific Data.
I2C Address: From 0x50 to 0x57;
EEPROM
eMMC/ NAND/ SPI-Flash
CSI-CAMERA
I2C Address: 0x30
WiFi&BT
Extension
UEXT & DBG-Uart
LED
Fiducials
Boot Order: SDC0 -> SDC2 -> SPI0 -> USB

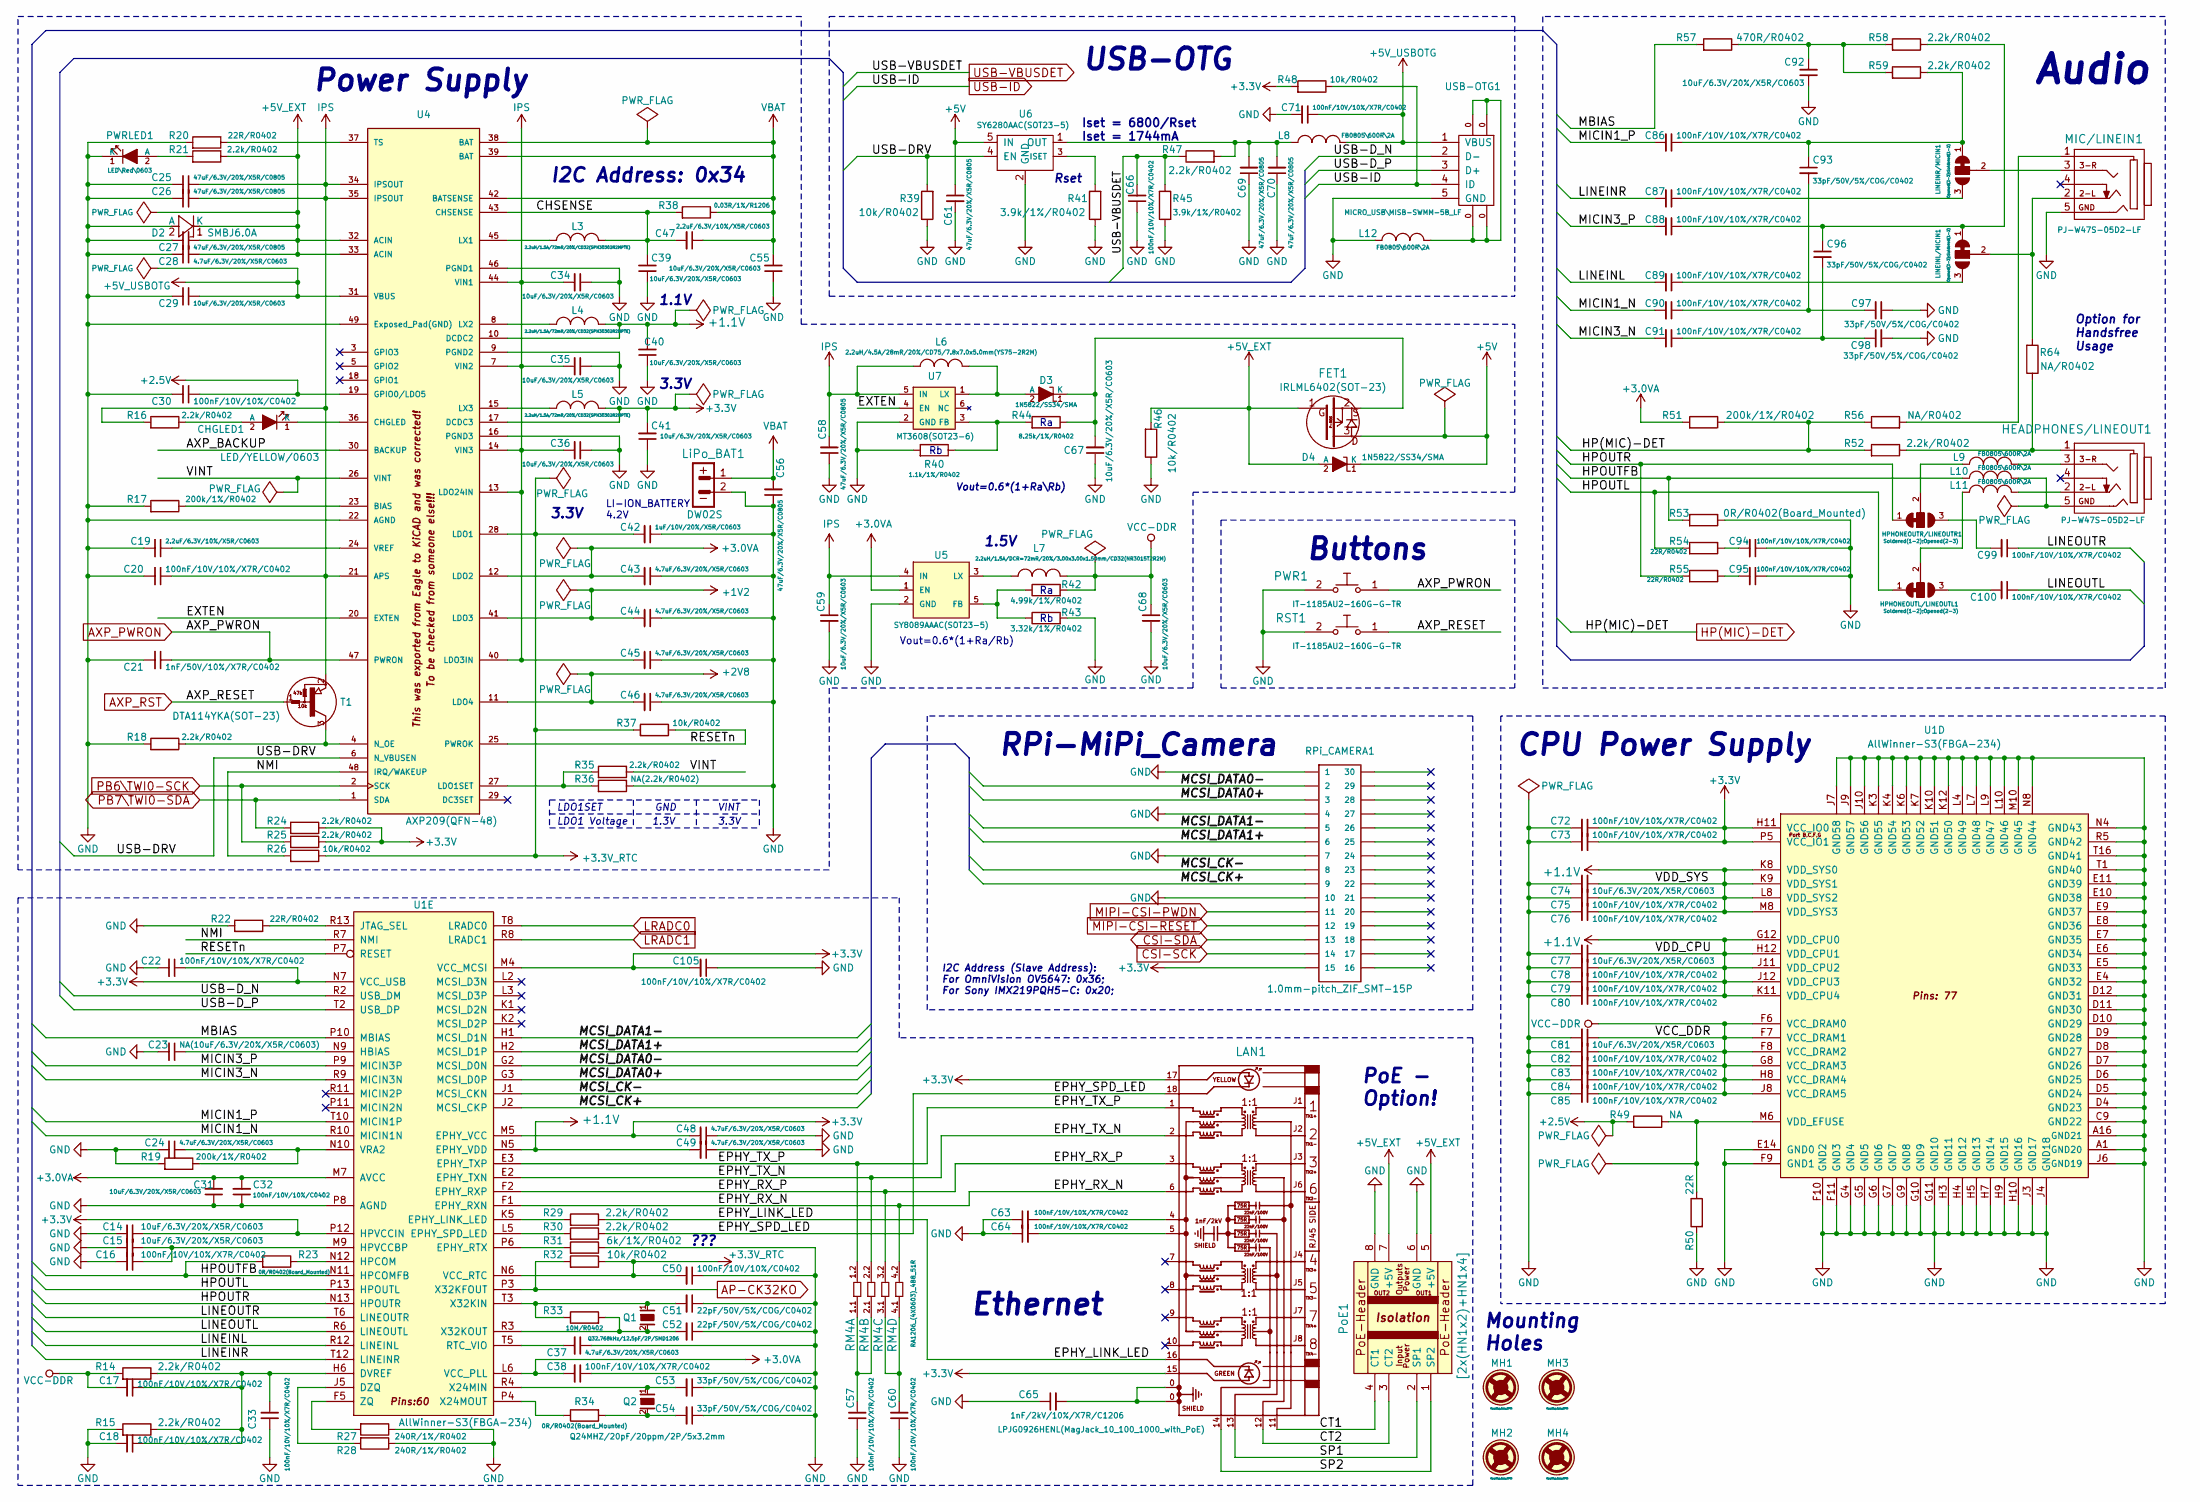
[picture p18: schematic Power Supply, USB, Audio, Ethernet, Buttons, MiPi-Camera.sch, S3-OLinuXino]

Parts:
C14, C15, C29, C31, C34, C35, C36, C39, C40, C41, C55, C59, C67, C68, C74, C77, C81, C92: 10uF/6.3V/20%/X5R/C0603; C_0603_5MIL_DWS
C16, C17, C18, C20, C22, C33, C38, C57, C60, C63, C64, C66, C71, C72, C73, C75, C76, C78, C79, C80, C82, C83, C84, C85, C86, C87, C88, C89, C90, C91, C94, C95, C99, C100, C105: 100nF/10V/10%/X7R/C0402; C_0402_5MIL_DWS
C19, C47: 2.2uF/6.3V/10%/X5R/C0603; C_0603_5MIL_DWS
C21: 1nF/50V/10%/X7R/C0402; C_0402_5MIL_DWS
C23: NA(10uF/6.3V/20%/X5R/C0603); C_0603_5MIL_DWS
C24, C28, C37, C43, C44, C45, C46, C48, C49: 4.7uF/6.3V/20%/X5R/C0603; C_0603_5MIL_DWS
C25, C26, C27, C56, C58, C61, C69, C70: 47uF/6.3V/20%/X5R/C0805; C_0805_5MIL_DWS
C30, C32, C50: 100nF/10V/10%/C0402; C_0402_5MIL_DWS
C42: 1uF/10V/20%/X5R/C0603; C_0603_5MIL_DWS
C51, C52: 22pF/50V/5%/COG/C0402; C_0402_5MIL_DWS
C53, C54, C93, C96, C97, C98: 33pF/50V/5%/COG/C0402; C_0402_5MIL_DWS
C65: 1nF/2kV/10%/X7R/C1206; C_1206_5MIL_DWS_ISO
CHGLED1: LED/YELLOW/0603; LED_0603_KA
D2: SMBJ6.0A; DO214AA_1(K)-2(A)
D3, D4: 1N5822/SS34/SMA; SMA-KA
FET1: IRLML6402(SOT-23); SOT23
HEADPHONES/LINEOUT1: PJ-W47S-05D2-LF; PJ-W47S-05D2-LF_5PIN_V2
HPHONEOUTL/LINEOUTL1: Soldered(1-2);Opened(2-3); SJ_2_SMALL
HPHONEOUTR/LINEOUTR1: Soldered(1-2);Opened(2-3); SJ_2_SMALL
L3, L4, L5: 2.2uH/1.5A/72mR/20%/CD32(SPN30302R2MPTE); CD32
L6: 2.2uH/4.5A/28mR/20%/CD75/7.8x7.0x5.0mm(YS75-2R2M); YS75_7X8MM
L7: 2.2uH/1.5A/DCR=72mR/20%/3.00x3.00x1.50mm/CD32(NR3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; CD32
L8, L9, L10, L11, L12: FB0805\\600R\\2A; L_0805_5MIL_DWS
LAN1: LPJG0926HENL(MagJack_10_100_1000_with_PoE)
LINEINL/MICIN1: Opened(2-3);Soldered(1-2); SJ_2_SMALL
LINEINR/MICIN1: Opened(2-3);Soldered(1-2); SJ_2_SMALL
LiPo_BAT1: DW02S; LIPO_BAT_VERTICAL_DW02S
MH1, MH2, MH3, MH4: Mounting_Hole_NPTH; Mounting_Hole_Drill-3.3mm_Clerance-7mm
MIC/LINEIN1: PJ-W47S-05D2-LF; PJ-W47S-05D2-LF_5PIN_V2
PWR1: IT-1185AU2-160G-G-TR; IT1185AU2_V2
PWRLED1: LED\\Red\\0603; LED_0603_KA
PoE1: [2x(HN1x2)+HN1x4]; PoE[2x(HN1x2)+HN1x4]
Q1: Q32.768kHz/12.5pF/2P/SMD1206; CM7V-T1A(Crystal_Package-1206_3.20x1.50x0.65mm)
Q2: Q24MHZ/20pF/20ppm/2P/5x3.2mm; HCX-4S_2Pins_5.0x3.2mm_TEST
R14, R15, R16, R18, R21, R24, R25, R29, R30, R35, R47, R52, R58, R59: 2.2k/R0402; R_0402_5MIL_DWS
R17, R19, R51: 200k/1%/R0402; R_0402_5MIL_DWS
R20, R22, R54, R55: 22R/R0402; R_0402_5MIL_DWS
R23, R34, R53: 0R/R0402(Board_Mounted); R_0402_5MIL_0R(Board_Mounted)
R26, R32, R37, R39, R46, R48: 10k/R0402; R_0402_5MIL_DWS
R27, R28: 240R/1%/R0402; R_0402_5MIL_DWS
R31: 6k/1%/R0402; R_0402_5MIL_DWS
R33: 10M/R0402; R_0402_5MIL_DWS
R36: NA(2.2k/R0402); R_0402_5MIL_DWS
R38: 0.03R/1%/R1206; R_1206_5MIL_DWS
R40: 1.1k/1%/R0402; R_0402_5MIL_DWS
R41, R45: 3.9k/1%/R0402; R_0402_5MIL_DWS
R42: 4.99k/1%/R0402; R_0402_5MIL_DWS
R43: 3.32k/1%/R0402; R_0402_5MIL_DWS
R44: 8.25k/1%/R0402; R_0402_5MIL_DWS
R49: NA; R_0402_5MIL_DWS
R50: 22R; R_0402_5MIL_DWS
R56, R64: NA/R0402; R_0402_5MIL_DWS
R57: 470R/R0402; R_0402_5MIL_DWS
RM4: RA1206_(4X0603)_4B8_51R; RA1206_(4X0603)_4B8_xx
RPi_CAMERA1: 1.0mm-pitch_ZIF_SMT-15P; TE_1-1734248-5
RST1: IT-1185AU2-160G-G-TR; IT1185AU2_V2
T1: DTA114YKA(SOT-23); SOT23
U1: AllWinner-S3(FBGA-234); FBGA-234(Pitch-0.65mm_Pad-0.3mm_11x11x1.08mm)
U4: AXP209(QFN-48); QFN48-6x6mm-OLIMEX_V2
U5: SY8089AAAC(SOT23-5); SOT-23-5
U6: SY6280AAC(SOT23-5); SOT-23-5
U7: MT3608(SOT23-6); SOT23-6
USB-OTG1: MICRO_USB\\MISB-SWMM-5B_LF; USB-MICRO_MISB-SWMM-5B_LF

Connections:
+1.1V: C40.2, C49.2, C74.1, C75.1, C76.1, C77.1, C78.1, C79.1, C80.1, L4.2, U1.G12 (VDD_CPU0), U1.H12 (VDD_CPU1), U1.J11 (VDD_CPU2), U1.J12 (VDD_CPU3), U1.K8 (VDD_SYS0), U1.K9 (VDD_SYS1), U1.K11 (VDD_CPU4), U1.L8 (VDD_SYS2), U1.M8 (VDD_SYS3), U1.N5 (EPHY_VDD), U4.10 (DCDC2)
+1V2: C44.2, U4.41 (LDO3); also elsewhere on the board
+2.5V: C30.1, R49.2, U4.19 (GPIO0/LDO5)
+2V8: C46.2, U4.11 (LDO4); also elsewhere on the board
+3.0VA: C31.2, C32.2, C38.2, C43.2, R51.2, U1.L6 (VCC_PLL), U1.M7 (AVCC), U4.12 (LDO2), U5.1 (EN); also elsewhere on the board
+3.3V_RTC: C42.2, C50.2, R26.1, R32.1, R37.2, U1.N6 (VCC_RTC), U4.28 (LDO1); also elsewhere on the board
+3V3: C14.1, C22.1, C41.2, C48.2, C72.1, C73.1, C105.2, L5.2, LAN1.15 (G-K), LAN1.17 (Y-K), R24.1, R25.1, R48.2, RPi_CAMERA1.15, U1.H11 (VCC_IO0), U1.L11 (VCC-PD0), U1.L12 (VCC-PD1), U1.M4 (VCC_MCSI), U1.M5 (EPHY_VCC), U1.M11 (VCC-PE0), U1.M12 (VCC-PE1), U1.N7 (VCC_USB), U1.P5 (VCC_IO1), U1.P12 (HPVCCIN), U4.17 (DCDC3); also elsewhere on the board
+5V: C61.1, D4.1 (K), FET1.3, U6.5 (IN); also elsewhere on the board
+5V_EXT: C27.1, C28.1, D2.1 (K), D4.2 (A), FET1.1, PoE1.5 (+5V), PoE1.7 (+5V), R21.1, R46.2, U4.32 (ACIN), U4.33 (ACIN); also elsewhere on the board
+5V_USBOTG: C29.1, C71.1, L8.2, U4.31 (VBUS), USB-OTG1.1 (VBUS)
/AP-WAKE-BT: U1.F12 (PE4/CSI_D0/LCD_D2); also elsewhere on the board
/BT-DIS-N: U1.C13 (PE5/CSI_D1/LCD_D3); also elsewhere on the board
/BT-PCM-CLK: U1.P14 (PG11/PCM_BCLK/PG_EINT11); also elsewhere on the board
/BT-PCM-DIN: U1.T15 (PG12/PCM_DOUT/PG_EINT12); also elsewhere on the board
/BT-PCM-DOUT: U1.M13 (PG13/PCM_DIN/PG_EINT13); also elsewhere on the board
/BT-PCM-SYNC: U1.T14 (PG10/PCM_SYNC/PG_EINT10); also elsewhere on the board
/BT-UART-CTS: U1.B8 (PB2/UART2_RTS/PB_EINT2); also elsewhere on the board
/BT-UART-RX: U1.B3 (PB0/UART2_TX/PB_EINT0); also elsewhere on the board
/BT-UART-TX: U1.B4 (PB1/UART2_RX/PB_EINT1); also elsewhere on the board
/BT-WAKE-AP: U1.N14 (PG8/UART1_RTS/PG_EINT8); also elsewhere on the board
/CAM-PWDN: U1.D14 (PE17/CSI_D13/LCD_D19); also elsewhere on the board
/CAM-RST: U1.D15 (PE16/CSI_D12/LCD_D18); also elsewhere on the board
/CSI-D2: U1.E12 (PE6/CSI_D2/LCD_D4); also elsewhere on the board
/CSI-D3: U1.G15 (PE7/CSI_D3/LCD_D5); also elsewhere on the board
/CSI-D4: U1.H13 (PE8/CSI_D4/LCD_D6); also elsewhere on the board
/CSI-D5: U1.E13 (PE9/CSI_D5/LCD_D7); also elsewhere on the board
/CSI-D6: U1.J13 (PE10/CSI_D6/LCD_D10); also elsewhere on the board
/CSI-D7: U1.H14 (PE11/CSI_D7/LCD_D11); also elsewhere on the board
/CSI-D8: U1.G14 (PE12/CSI_D8/LCD_D12); also elsewhere on the board
/CSI-D9: U1.L13 (PE13/CSI_D9/LCD_D13); also elsewhere on the board
/CSI-D10: U1.L16 (PE14/CSI_D10/LCD_D14); also elsewhere on the board
/CSI-D11: U1.K13 (PE15/CSI_D11/LCD_D15); also elsewhere on the board
/CSI-HSYNC: U1.C14 (PE2/CSI_HSYNC/LCD_HSYNC); also elsewhere on the board
/CSI-MCLK: U1.G13 (PE1/CSI_MCLK/LCD_DE); also elsewhere on the board
/CSI-PCLK: U1.F14 (PE0/CSI_PCLK/LCD_CLK); also elsewhere on the board
/CSI-VSYNC: U1.F15 (PE3/CSI_VSYNC/LCD_VSYNC); also elsewhere on the board
/CTP-INT: U1.A2 (PB13/JTAG_DI/PB_EINT13); also elsewhere on the board
/CTP-RST: U1.H15 (PE20/CSI_FIELD/CSI_MIPI_MCLK); also elsewhere on the board
/GPIO_LED: U1.C7 (PB5/PWM1/PB_EINT5); also elsewhere on the board
/LCD-PWM: U1.C8 (PB4/PWM0/PB_EINT4); also elsewhere on the board
/LCD_CLK: U1.A11 (PD18/LCD_CLK/LVDS_VPC); also elsewhere on the board
/LCD_D2: U1.K15 (PD0/LCD_D2/RGMII_RXD3/RMII_NULL); also elsewhere on the board
/LCD_D3: U1.C11 (PD1/LCD_D3/RGMII_RXD2/RMII_NULL); also elsewhere on the board
/LCD_D4: U1.J14 (PD2/LCD_D4/RGMII_RXD1/RMII_RXD1); also elsewhere on the board
/LCD_D5: U1.J15 (PD3/LCD_D5/RGMII_RXD0/RMII_RXD0); also elsewhere on the board
/LCD_D6: U1.B16 (PD4/LCD_D6/RGMII_RXCK/RMII_NULL); also elsewhere on the board
/LCD_D7: U1.C16 (PD5/LCD_D7/RGMII_RXCTL/RMII_NULL); also elsewhere on the board
/LCD_D10: U1.B9 (PD6/LCD_D10/RGMII_NULL/RMII_RXER); also elsewhere on the board
/LCD_D11: U1.A9 (PD7/LCD_D11/RGMII_TXD3/RMII_NULL); also elsewhere on the board
/LCD_D12: U1.C15 (PD8/LCD_D12/RGMII_TXD2/RMII_NULL); also elsewhere on the board
/LCD_D13: U1.L15 (PD9/LCD_D13/RGMII_TXD1/RMII_TXD1); also elsewhere on the board
/LCD_D14: U1.A15 (PD10/LCD_D14/RGMII_TXD0/RMII_TXD0); also elsewhere on the board
/LCD_D15: U1.B15 (PD11/LCD_D15/RGMII_NULL/RMII_CRS_D); also elsewhere on the board
/LCD_D18: U1.B14 (PD12/LCD_D18/LVDS_VP0/RGMII_TXCK/RMII_T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); also elsewhere on the board
/LCD_D19: U1.A14 (PD13/LCD_D19/LVDS_DN0/RGMII_TXCTL/RMII_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); also elsewhere on the board
/LCD_D20: U1.B13 (PD14/LCD_D20/LVDS_VP1/RGMII_NULL/RMII_N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); also elsewhere on the board
/LCD_D21: U1.A13 (PD15/LCD_D21/LVDS_VN1/RGMII_CLKIN/RMII_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); also elsewhere on the board
/LCD_D22: U1.B12 (PD16/LCD_D22/LVDS_VP2/MDC); also elsewhere on the board
/LCD_D23: U1.C12 (PD17/LCD_D23/LVDS_VN2/MDIO); also elsewhere on the board
/LCD_DE: U1.B11 (PD19/LCD_DE/LVDS_VNC); also elsewhere on the board
/LCD_HSYNC: U1.C10 (PD20/LCD_HSYNC/LVDS_VP3); also elsewhere on the board
/LCD_PWR: U1.E15 (PE18/CSI_D14/LCD_D20); also elsewhere on the board
/LCD_VSYNC: U1.B10 (PD21/LCD_VSYNC/LVDS_VN3); also elsewhere on the board
/PB3: U1.C4 (PB3/UART2_CTS/PB_EINT3); also elsewhere on the board
/Power Supply, USB, Audio, Ethernet, Buttons, MiPi-Camera/AXP_BACKUP: U4.30 (BACKUP)
/Power Supply, USB, Audio, Ethernet, Buttons, MiPi-Camera/CHSENSE: C39.2, C47.2, L3.2, R38.2, U4.43 (CHSENSE)
/Power Supply, USB, Audio, Ethernet, Buttons, MiPi-Camera/CT1: LAN1.11 (VC1), PoE1.4 (CT1)
/Power Supply, USB, Audio, Ethernet, Buttons, MiPi-Camera/CT2: LAN1.12 (VC2), PoE1.3 (CT2)
/Power Supply, USB, Audio, Ethernet, Buttons, MiPi-Camera/EPHY_LINK_LED: LAN1.16 (G-A), R29.1
/Power Supply, USB, Audio, Ethernet, Buttons, MiPi-Camera/EPHY_RX_N: LAN1.6 (TD2-), RM4.4.2, U1.F1 (EPHY_RXN)
/Power Supply, USB, Audio, Ethernet, Buttons, MiPi-Camera/EPHY_RX_P: LAN1.3 (TD2+), RM4.3.2, U1.F2 (EPHY_RXP)
/Power Supply, USB, Audio, Ethernet, Buttons, MiPi-Camera/EPHY_SPD_LED: LAN1.18 (Y-A), R30.1
/Power Supply, USB, Audio, Ethernet, Buttons, MiPi-Camera/EPHY_TX_N: LAN1.2 (TD1-), RM4.2.2, U1.E2 (EPHY_TXN)
/Power Supply, USB, Audio, Ethernet, Buttons, MiPi-Camera/EPHY_TX_P: LAN1.1 (TD1+), RM4.1.2, U1.E3 (EPHY_TXP)
/Power Supply, USB, Audio, Ethernet, Buttons, MiPi-Camera/EXTEN: U4.20 (EXTEN), U7.4 (EN)
/Power Supply, USB, Audio, Ethernet, Buttons, MiPi-Camera/HPOUTFB: L10.1, R23.2, R53.2, U1.N11 (HPCOMFB)
/Power Supply, USB, Audio, Ethernet, Buttons, MiPi-Camera/HPOUTL: HPHONEOUTL/LINEOUTL1.1, R54.2, U1.P13 (HPOUTL)
/Power Supply, USB, Audio, Ethernet, Buttons, MiPi-Camera/HPOUTR: HPHONEOUTR/LINEOUTR1.1, R55.2, U1.N13 (HPOUTR)
/Power Supply, USB, Audio, Ethernet, Buttons, MiPi-Camera/LINEINL: C89.2, U1.R12 (LINEINL)
/Power Supply, USB, Audio, Ethernet, Buttons, MiPi-Camera/LINEINR: C87.2, U1.T12 (LINEINR)
/Power Supply, USB, Audio, Ethernet, Buttons, MiPi-Camera/LINEOUTL: C100.1, U1.R6 (LINEOUTL)
/Power Supply, USB, Audio, Ethernet, Buttons, MiPi-Camera/LINEOUTR: C99.1, U1.T6 (LINEOUTR)
/Power Supply, USB, Audio, Ethernet, Buttons, MiPi-Camera/MBIAS: R57.2, U1.P10 (MBIAS)
/Power Supply, USB, Audio, Ethernet, Buttons, MiPi-Camera/MCSI_CK+: RPi_CAMERA1.9, U1.J2 (MCSI_CKP)
/Power Supply, USB, Audio, Ethernet, Buttons, MiPi-Camera/MCSI_CK-: RPi_CAMERA1.8, U1.J1 (MCSI_CKN)
/Power Supply, USB, Audio, Ethernet, Buttons, MiPi-Camera/MCSI_DATA0+: RPi_CAMERA1.3, U1.G3 (MCSI_D0P)
/Power Supply, USB, Audio, Ethernet, Buttons, MiPi-Camera/MCSI_DATA0-: RPi_CAMERA1.2, U1.G2 (MCSI_D0N)
/Power Supply, USB, Audio, Ethernet, Buttons, MiPi-Camera/MCSI_DATA1+: RPi_CAMERA1.6, U1.H2 (MCSI_D1P)
/Power Supply, USB, Audio, Ethernet, Buttons, MiPi-Camera/MCSI_DATA1-: RPi_CAMERA1.5, U1.H1 (MCSI_D1N)
/Power Supply, USB, Audio, Ethernet, Buttons, MiPi-Camera/MICIN1_N: C90.2, U1.R10 (MICIN1N)
/Power Supply, USB, Audio, Ethernet, Buttons, MiPi-Camera/MICIN1_P: C86.2, U1.T10 (MICIN1P)
/Power Supply, USB, Audio, Ethernet, Buttons, MiPi-Camera/MICIN3_N: C91.2, U1.R9 (MICIN3N)
/Power Supply, USB, Audio, Ethernet, Buttons, MiPi-Camera/MICIN3_P: C88.2, U1.P9 (MICIN3P)
/Power Supply, USB, Audio, Ethernet, Buttons, MiPi-Camera/NMI: R26.2, U1.R7 (NMI), U4.48 (IRQ/WAKEUP)
/Power Supply, USB, Audio, Ethernet, Buttons, MiPi-Camera/RESETn: R37.1, U1.P7 (RESET), U4.25 (PWROK)
/Power Supply, USB, Audio, Ethernet, Buttons, MiPi-Camera/SP1: LAN1.13 (VC3), PoE1.2 (SP1)
/Power Supply, USB, Audio, Ethernet, Buttons, MiPi-Camera/SP2: LAN1.14 (VC4), PoE1.1 (SP2)
/Power Supply, USB, Audio, Ethernet, Buttons, MiPi-Camera/USB-DRV: R39.2, U4.6 (N_VBUSEN), U6.4 (EN)
/Power Supply, USB, Audio, Ethernet, Buttons, MiPi-Camera/USB-D_N: U1.R2 (USB_DM), USB-OTG1.2 (D-)
/Power Supply, USB, Audio, Ethernet, Buttons, MiPi-Camera/USB-D_P: U1.T2 (USB_DP), USB-OTG1.3 (D+)
/Power Supply, USB, Audio, Ethernet, Buttons, MiPi-Camera/VINT: R35.1, U4.26 (VINT)
/SDC0-CLK: U1.P2 (PF2/SDC0_CLK/UART0_TX); also elsewhere on the board
/SDC0-CMD: U1.N2 (PF3/SDC0_CMD/JTAG_DO); also elsewhere on the board
/SDC0-D0: U1.P1 (PF1/SDC0_D0/JTAG_DI); also elsewhere on the board
/SDC0-D1: U1.R1 (PF0/SDC0_D1/JTAG_MS); also elsewhere on the board
/SDC0-D2: U1.M2 (PF5/SDC0_D2/JTAG_CK); also elsewhere on the board
/SDC0-D3: U1.N3 (PF4/SDC0_D3/UART0_RX); also elsewhere on the board
/SDC0-DET#: U1.M1 (PF6); also elsewhere on the board
/SDC2-CLK\SPI0-MISO: U1.A3 (PC0/SDC2_CLK/SPI0_MISO); also elsewhere on the board
/SDC2-CMD\SPI0-CLK: U1.B2 (PC1/SDC2_CMD/SPI0_CLK); also elsewhere on the board
/SDC2-D0\SPI0-MOSI: U1.C2 (PC3/SDC2_D0/SPI0_MOSI); also elsewhere on the board
/SDC2-D1: U1.F3 (PC4/SDC2_D1); also elsewhere on the board
/SDC2-D2: U1.F4 (PC5/SDC2_D2); also elsewhere on the board
/SDC2-D3: U1.C1 (PC6/SDC2_D3); also elsewhere on the board
/SDC2-D4: U1.C3 (PC7/SDC2_D4); also elsewhere on the board
/SDC2-D5: U1.D3 (PC8/SDC2_D5); also elsewhere on the board
/SDC2-D6: U1.D2 (PC9/SDC2_D6); also elsewhere on the board
/SDC2-D7: U1.D1 (PC10/SDC2_D7); also elsewhere on the board
/SDC2-RST\SPI0-CS: U1.B1 (PC2/SDC2_RST/SPI0_CS); also elsewhere on the board
/UART1_RX: U1.M14 (PG7/UART1_RX/PG_EINT7); also elsewhere on the board
/UART1_TX: U1.M15 (PG6/UART1_TX/PG_EINT6); also elsewhere on the board
/WL-PMU-EN: U1.E16 (PE19/CSI_D15/LCD_D21); also elsewhere on the board
/WL-SDIO-CLK: U1.P16 (PG0/SDC1_CLK/PG_EINT0); also elsewhere on the board
/WL-SDIO-CMD: U1.N15 (PG1/SDC1_CMD/PG_EINT1); also elsewhere on the board
/WL-SDIO-D0: U1.P15 (PG2/SDC1_D0/PG_EINT2); also elsewhere on the board
/WL-SDIO-D1: U1.N16 (PG3/SDC1_D1/PG_EINT3); also elsewhere on the board
/WL-SDIO-D2: U1.R15 (PG4/SDC1_D2/PG_EINT4); also elsewhere on the board
/WL-SDIO-D3: U1.R16 (PG5/SDC1_D3/PG_EINT5); also elsewhere on the board
/WL-WAKE-AP: U1.C5 (PB11/JTAG_CK/PB_EINT11); also elsewhere on the board
AP-CK32KO: R32.2, U1.P3 (X32KFOUT); also elsewhere on the board
AXP_PWRON: C21.1, PWR1.1, U4.47 (PWRON); also elsewhere on the board
AXP_RST: RST1.1, T1.1 (B); also elsewhere on the board
CSI-SCK: RPi_CAMERA1.14, U1.G16 (PE21/CSI_SCK/TWI1_SCK/UART1_TX); also elsewhere on the board
CSI-SDA: RPi_CAMERA1.13, U1.J16 (PE22/CSI_SDA/TWI1_SDA/UART1_RX); also elsewhere on the board
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

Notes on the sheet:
Power Supply
LI-ION_BATTERY 4.2V
Iset = 6800/Rset Iset = 1744mA
Rset
LDO1 Voltage
1.1V
I2C Address: 0x34
GND
1.5V
Vout=0.6*(1+Ra/Rb)
3.3V
1.3V
VINT
LDO1SET
USB-OTG
Vout=0.6*(1+Ra\Rb)
???
RPi-MiPi_Camera
I2C Address (Slave Address): For OmniVision OV5647: 0x36; For Sony IMX219PQH5-C: 0x20;
Ethernet
PoE - Option!
Buttons
Option for Handsfree Usage
Audio
CPU Power Supply
Mounting Holes

Board: 6 copper layers, 232 parts (115 on the bottom side), 221 nets, no tracks yet.

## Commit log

2019-10-25 initial upload schematic and pcb placements
    [20PinMaleSmt.stp, BGA-256_11.0x11.0mm_Layout20x20_P0.5mm_Ball0.3mm_Pad0.25mm_NSMD.step, BL-R8723BT1module.STEP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]
2020-04-24 Release
    revision A release design
    [20PinMaleSmt.stp, BGA-256_11.0x11.0mm_Layout20x20_P0.5mm_Ball0.3mm_Pad0.25mm_NSMD.step, BL-R8723BT1module.STEP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]
